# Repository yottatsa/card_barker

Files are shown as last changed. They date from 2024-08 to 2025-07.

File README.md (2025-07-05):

# Card Barker OPL3 Sound Card

*WARNING: this project has manufacturability issues: Zilog and two Yamaha chips are virtually unobtainable*

* PCMCIA interface: [Zilog Z86017/Z16017](https://www.zilog.com/index.php?Itemid=26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)
* OPL3: Yamaha YMF289B-S and YAC516-E
* Amp: [Texas Instruments TPA152DR](http://www.ti.com/lit/gpn/tpa152)

Project status: devboard is working, card hw rev 2 is working, card hw rev 3 goes thru small reDfM. 

## How to run

1. After assembly, upload `fw/vew211.bpd` using `fw/hsc.zip/burner.exe`;
2. Enable using `dos/panas13.lzh/panasnd.exe`, it should start responding on `0x0388-0x038b`;
3. Run `dos/oplclone.zip/oplclone.exe`, it should produce ~460Hz sine.
4. Under Windows 95 and 98, `win9x` contains the proto-driver that only enables the port.

## PCBs
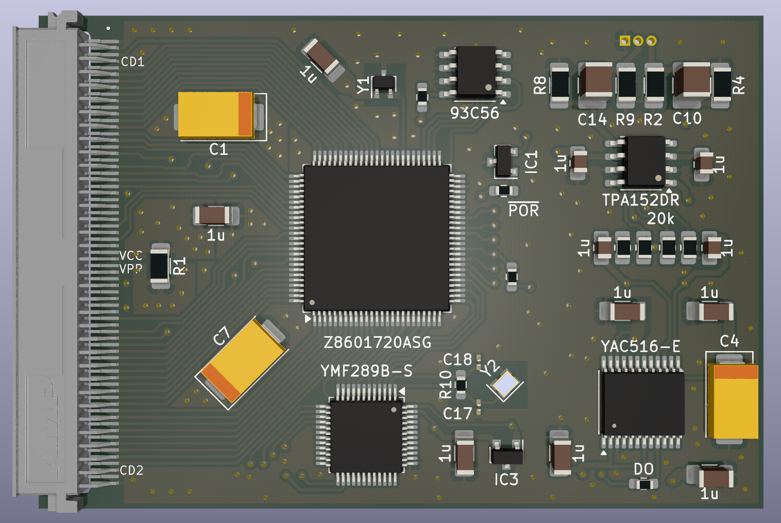
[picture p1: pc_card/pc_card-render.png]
Card

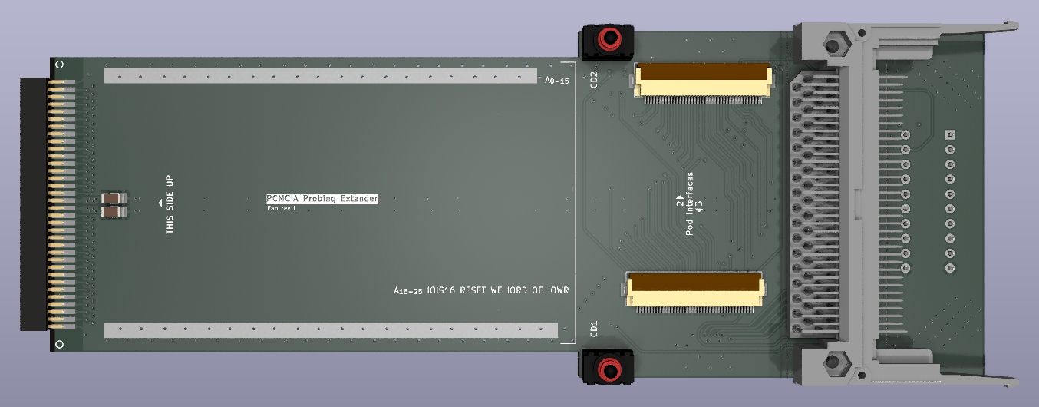
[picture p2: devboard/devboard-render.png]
devboard

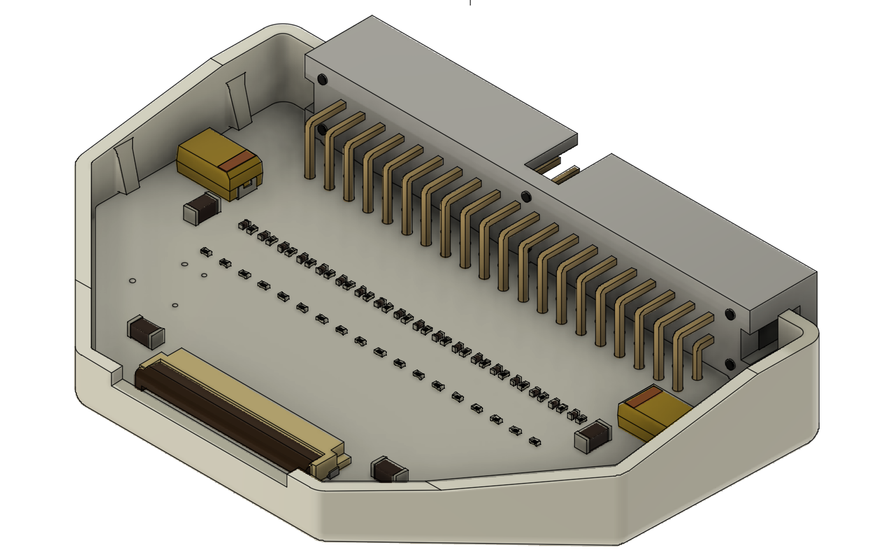
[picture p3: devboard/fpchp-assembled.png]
pod adapter


## Related projects

* [FMC-98 reverse engineering](https://github.com/AL-255/A2P1)

## License

Code, designs, and original research: CERN Open Hardware Licence Version 2 - Strongly Reciprocal
Supporting materials: fair use (archived to be protected from bitrot)

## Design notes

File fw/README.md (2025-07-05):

# Firmware misc

## `main.py` and `fw.bpd`
Fully generated driver

## `vew211*`

CIS dump for Panasonic Sound Card CF-VEW211.

## `hsc.zip`

3rd-party software that includes `BURNER.EXE`, utility to program the 93C56 EEPROM in-situ. Note that it should be run without Card Services running.

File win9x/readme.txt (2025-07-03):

pccard.inf
==========

This is a sample driver that should work with Panasonic CF-VEW211 card (see ../fw/vew211*) and generated driver (../fw/fw.bpd). The driver is generated using INF File Editor based on MSDN Library April 2000, https://library.thedatadungeon.com/msdn-2000-04/win95ddk/devdoc/live/win98ddk/devinst_12yd.htm and Windows 95 DDK docs/pnp.doc, https://archive.org/download/ms-win95-ddk.

todo
----
- figure out overrides, https://library.thedatadungeon.com/msdn-2000-04/win95ddk/devdoc/live/win98ddk/pnp_0hti.htm
- check if LogConfig is needed

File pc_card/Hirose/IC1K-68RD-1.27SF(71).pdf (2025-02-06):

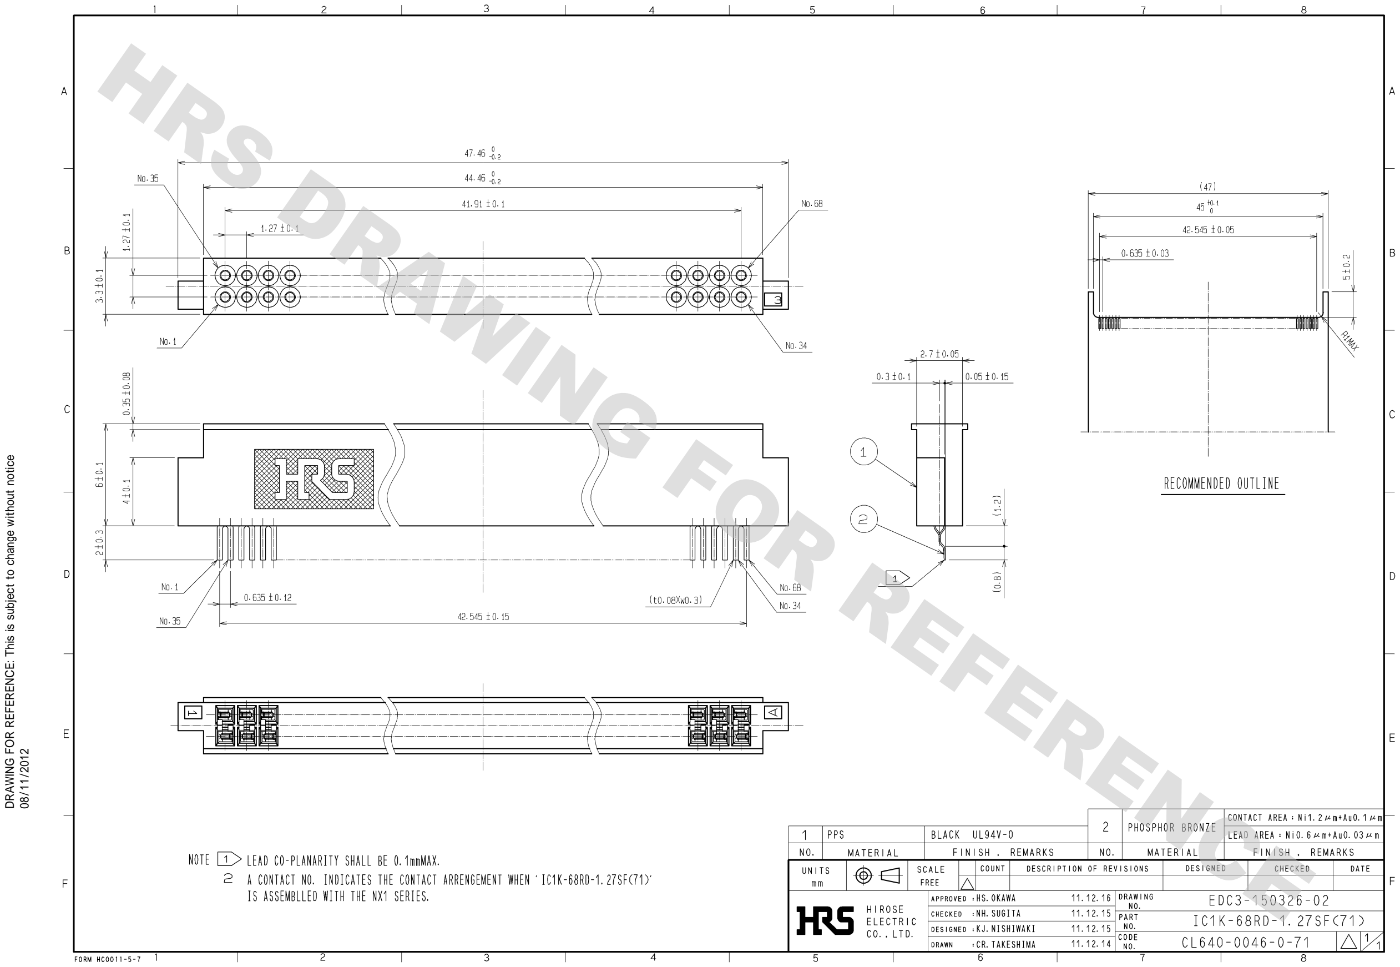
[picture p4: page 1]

# HRS DRAWING FOR REFERENCE

DRAWING FOR REFERENCE: This is subject to change without notice

08/11/2012

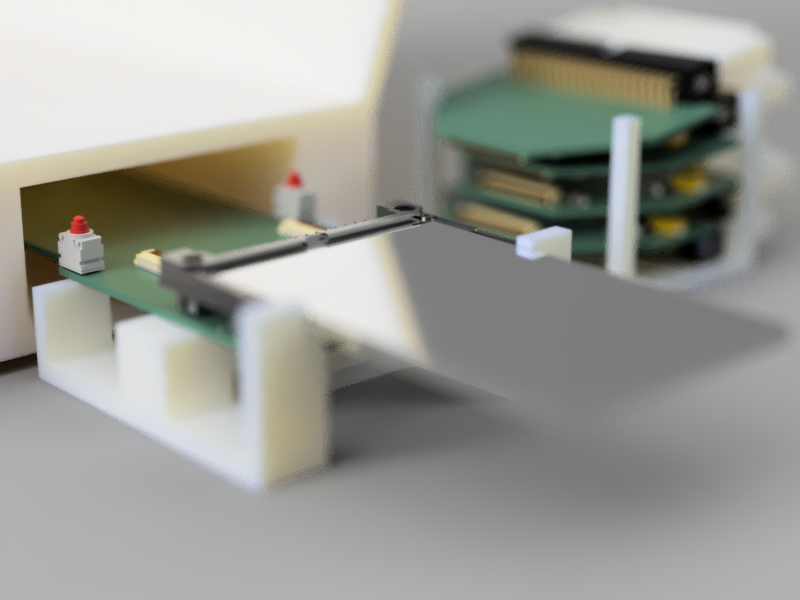
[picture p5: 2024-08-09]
devboard/dut_render.png

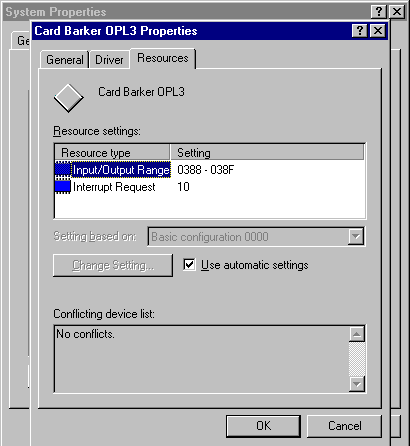
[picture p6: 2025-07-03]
win9x/sysprop-res.gif

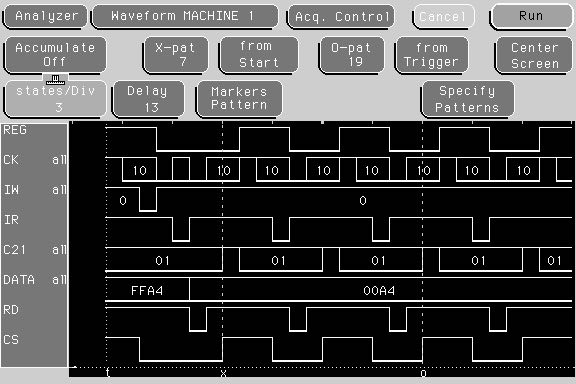
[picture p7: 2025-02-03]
hp1661c/waveform.jpg

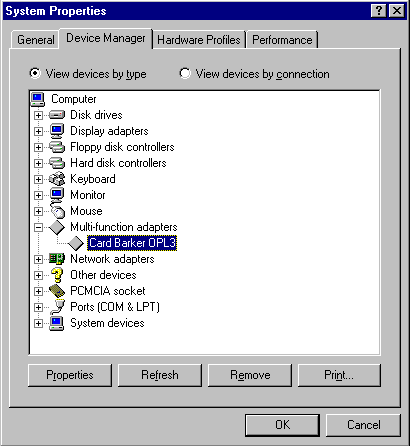
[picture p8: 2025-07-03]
win9x/sysprop.gif

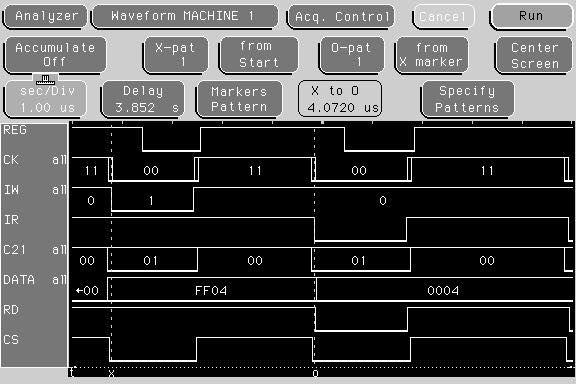
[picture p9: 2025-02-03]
hp1661c/timings.jpg

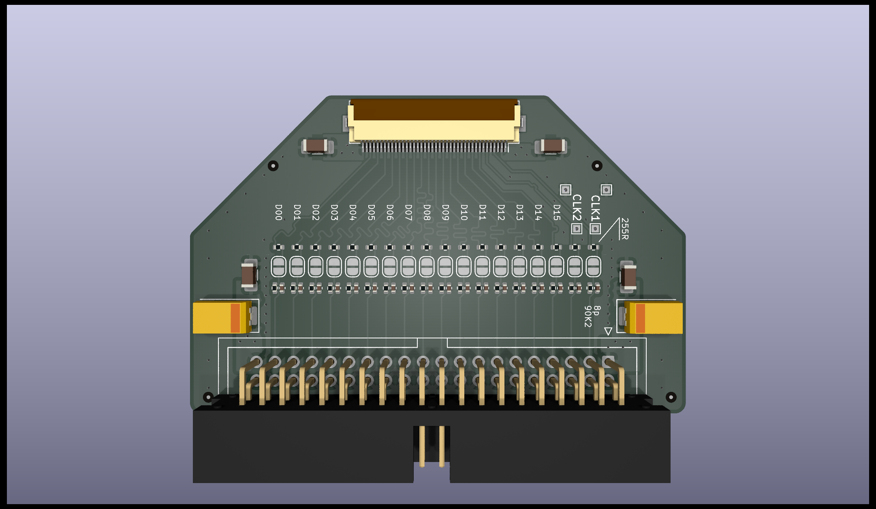
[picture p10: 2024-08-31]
devboard/fpchp-render.png

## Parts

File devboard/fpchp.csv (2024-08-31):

Id | Designator | Footprint | Quantity | Designation | Supplier and ref
1 | C15,C9,C7,C16,C5,C12,C8,C11,C2,C4,C10,C18,C3,C17,C14,C1,C13,C6 | C_0402_1005Metric | 18 | 8.2pF 0402 SMD Capacitor
2 | R24,R8,R19,R28,R32,R20,R12,R3,R16,R4,R7,R15,R27,R23,R11,R36,R31,R35 | R_0402_1005Metric | 18 | 249.0Ω 0402 SMD Resistor
3 | J1 | Hirose_FH12-40S-0.5SH_1x40-1MP_P0.50mm_Horizontal | 1 | Hirose Electric Co Ltd FH12A-40S-0.5SH(55)
4 | R30,R17,R14,R9,R34,R29,R25,R22,R6,R18,R26,R5,R13,R33,R2,R21,R1,R10 | R_0402_1005Metric | 18 | 90.9kΩ 0402 SMD Resistor
5 | C22,C19,C21,C20 | C_1206_3216Metric_Pad1.33x1.80mm_HandSolder | 4 | 1.0µF, 1206 SMD Capacitor
6 | CP2,CP1 | CP_EIA-7343-31_Kemet-D | 2 | 593D106X9035D2TE3 or other 10uF Electrolytic 16V or higher

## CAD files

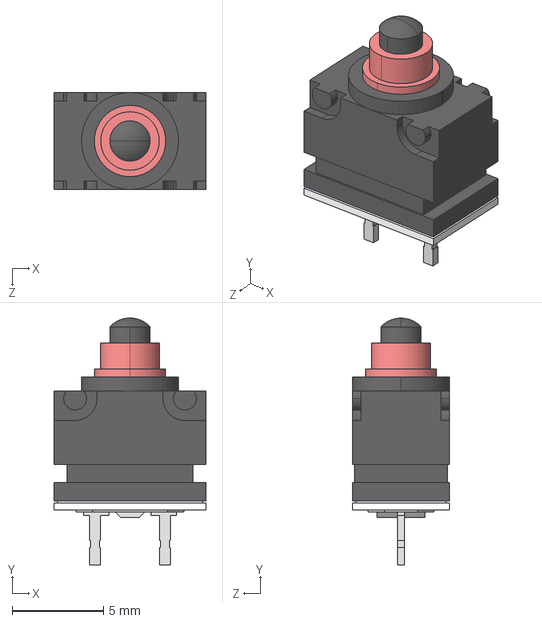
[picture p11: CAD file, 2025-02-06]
devboard/D2GW_A02D.step
8.30 x 13.5 x 5.30 mm
D2GW_A02D_BASE
D2GW_A02D_BUTTON

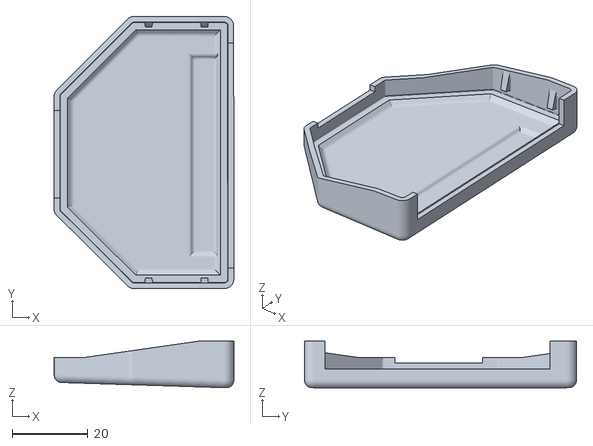
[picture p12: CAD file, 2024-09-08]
devboard/fpchp.stl
47.5 x 71.8 x 12.3

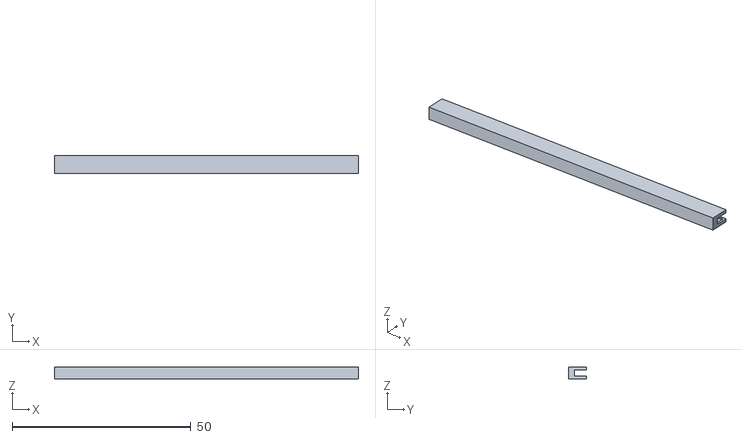
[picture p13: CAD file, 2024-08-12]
devboard/pcb_bracket.stl
85.0 x 5.00 x 3.30

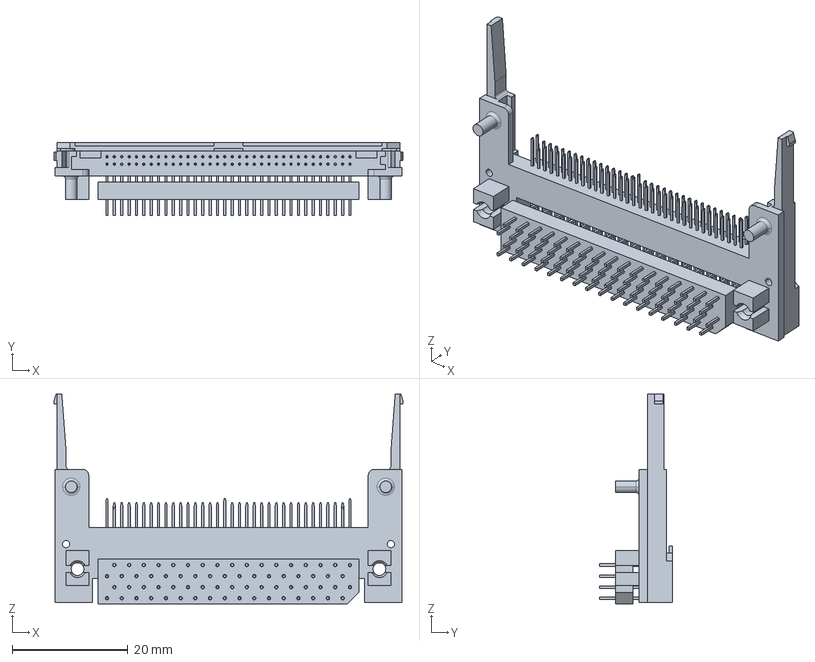
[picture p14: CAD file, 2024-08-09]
devboard/92140-010LF/92140-010LFc.stp
60.2 x 12.6 x 36.2 mm

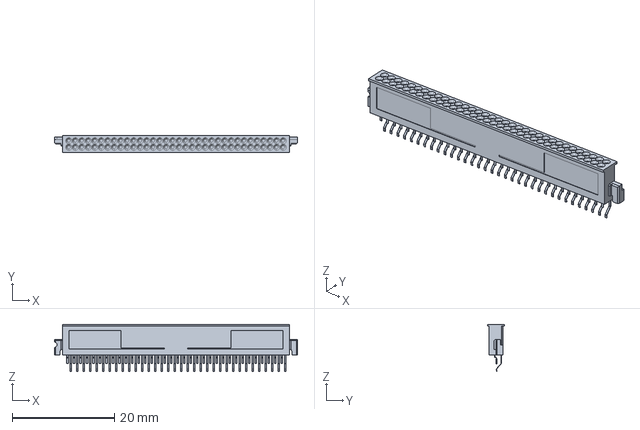
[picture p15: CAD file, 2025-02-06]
pc_card/TE/5146228-4.stp
47.5 x 3.30 x 9.25 mm

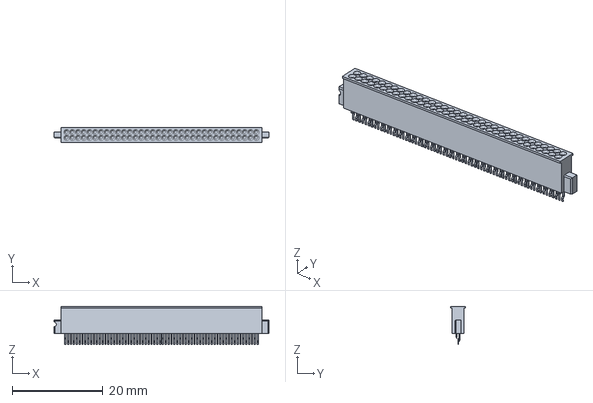
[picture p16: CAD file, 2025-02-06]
pc_card/TE/5146547-1.stp
47.5 x 3.30 x 8.48 mm

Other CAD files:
devboard/bottom-case.step

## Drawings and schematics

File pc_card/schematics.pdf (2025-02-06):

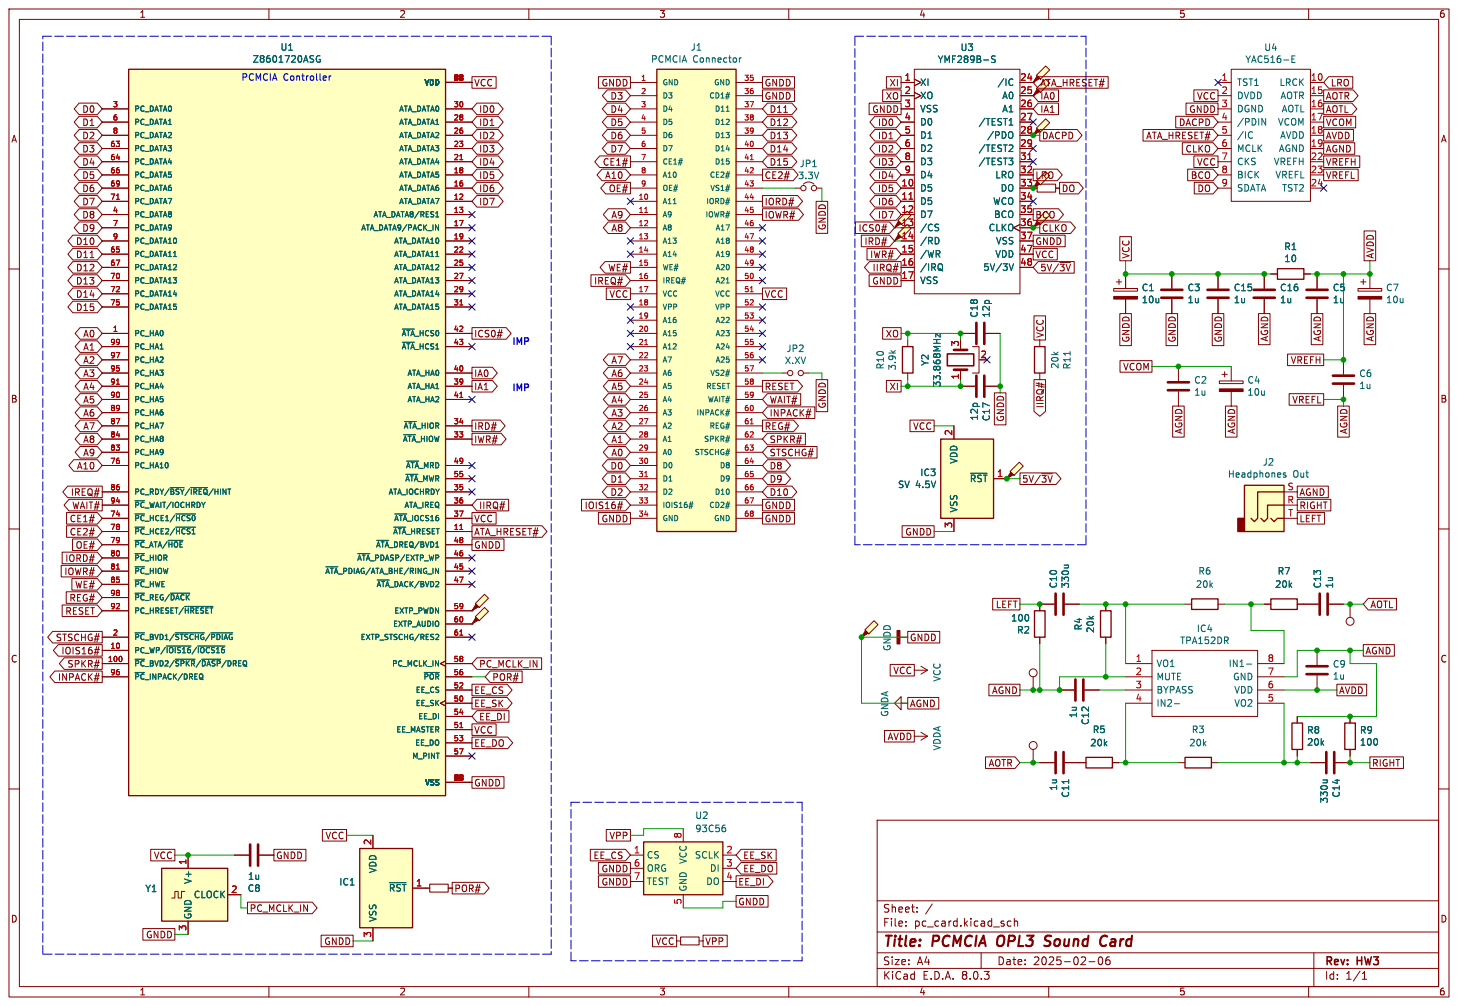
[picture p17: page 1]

INPACK# STSCHG# GNDD GNDD

Id: 1/1 Title: PCMCIA OPL3 Sound Card

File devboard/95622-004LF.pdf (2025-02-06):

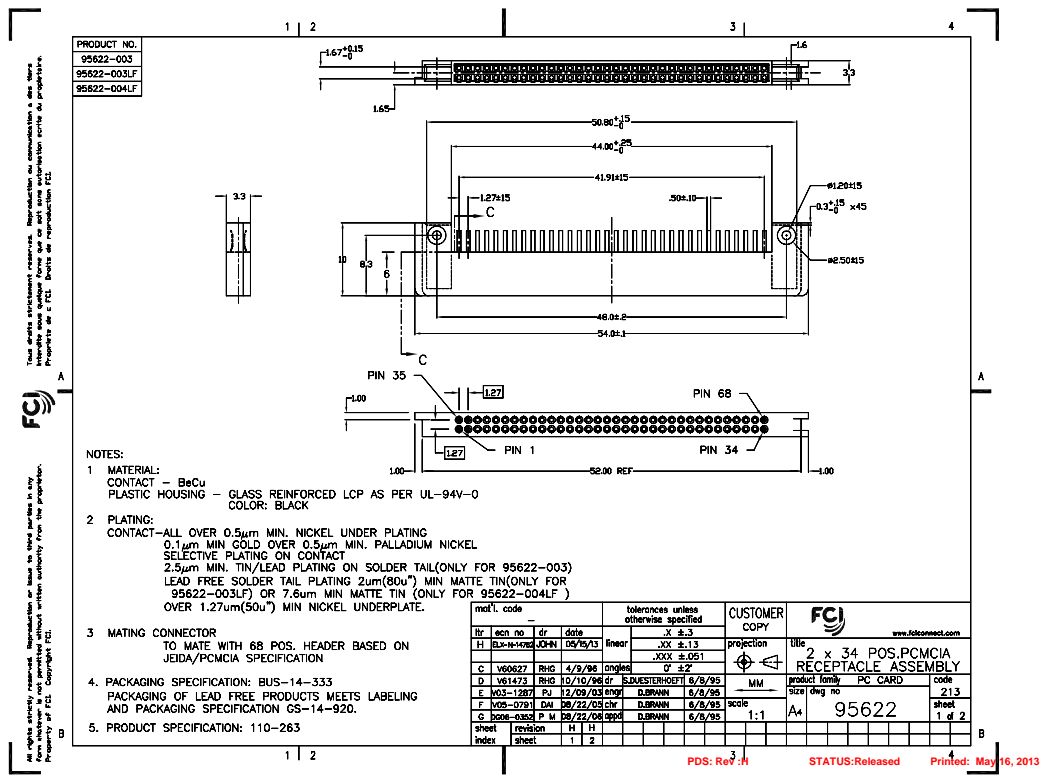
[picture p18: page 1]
PDS: Rev :H; STATUS:Released; Printed: May 16, 2013

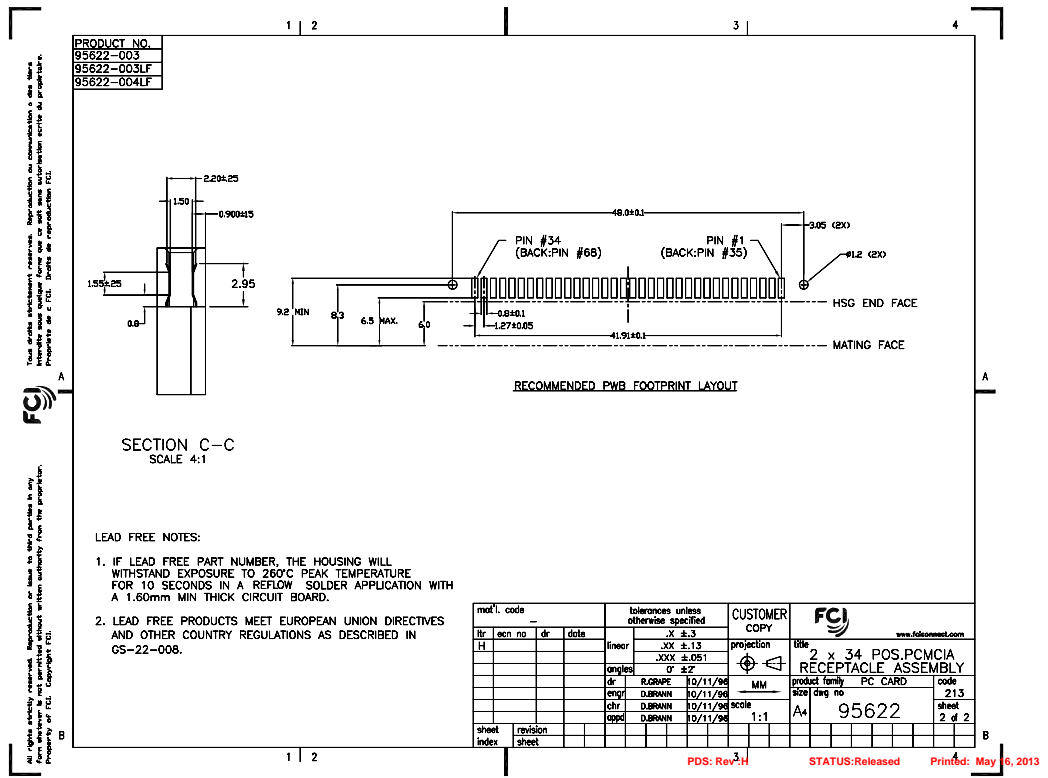
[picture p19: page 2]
PDS: Rev :H; STATUS:Released; Printed: May 16, 2013

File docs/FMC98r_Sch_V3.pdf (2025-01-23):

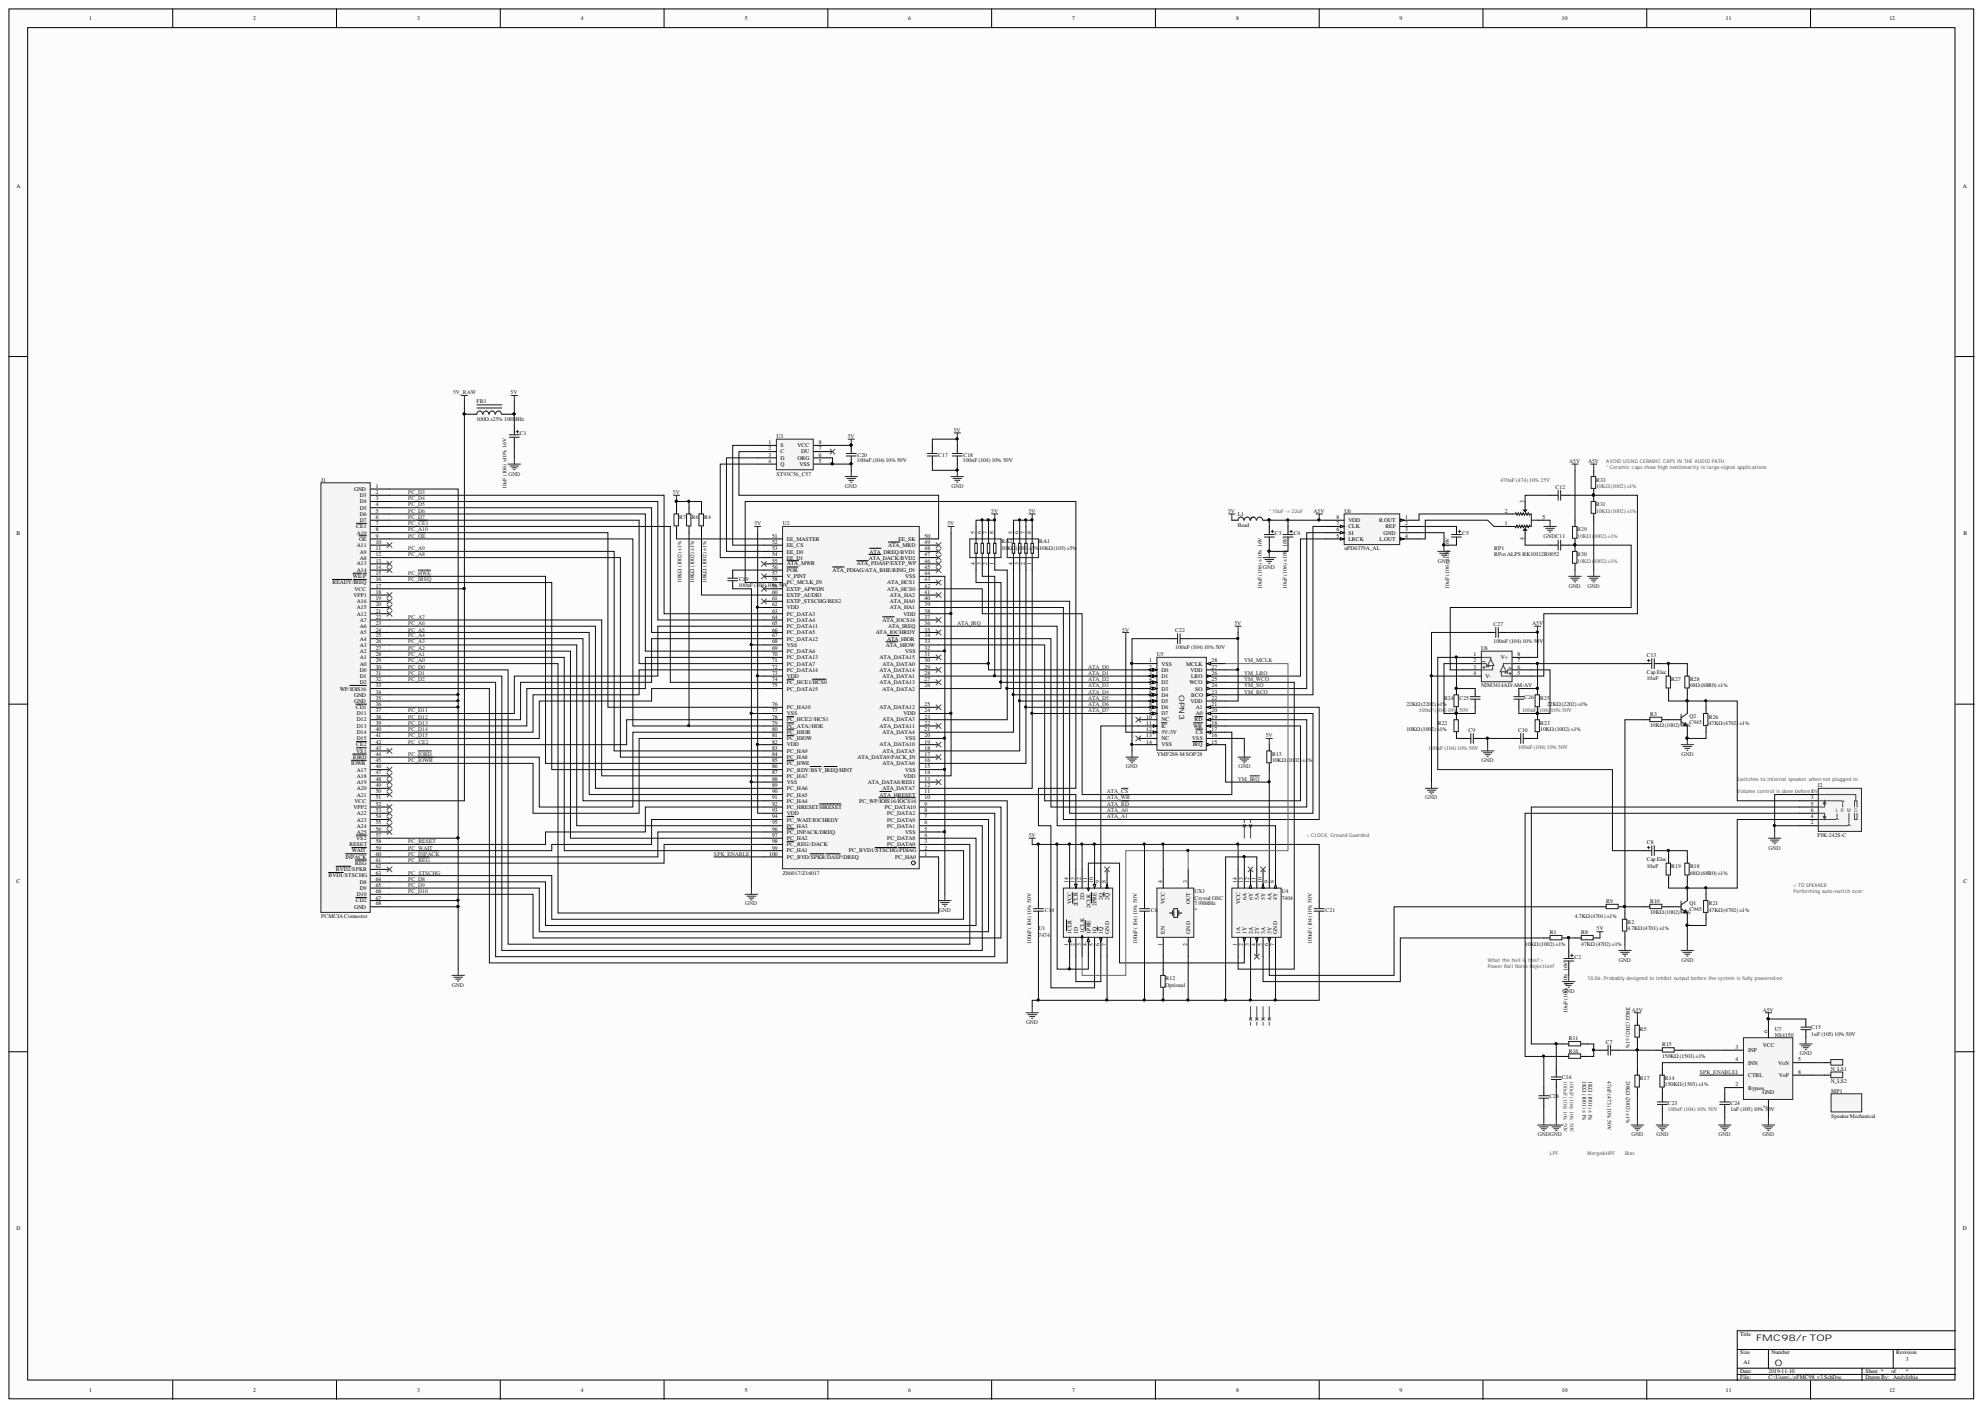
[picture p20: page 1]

150K Ω (1503) ±1% 4 | IN N VoN C T R L VoP Bypa s s D

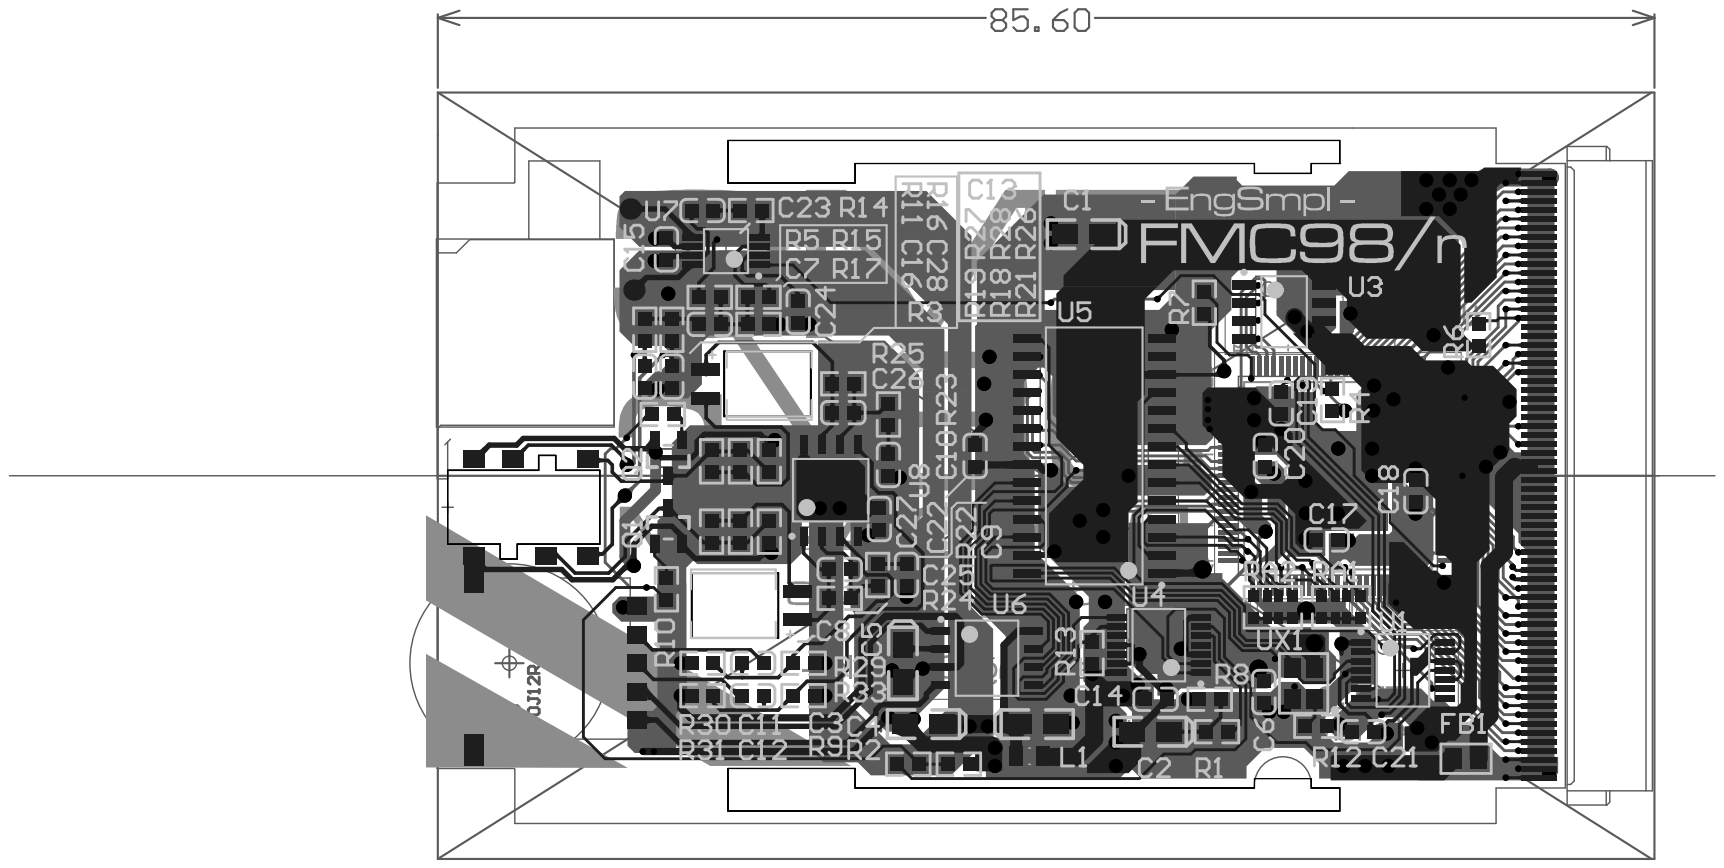
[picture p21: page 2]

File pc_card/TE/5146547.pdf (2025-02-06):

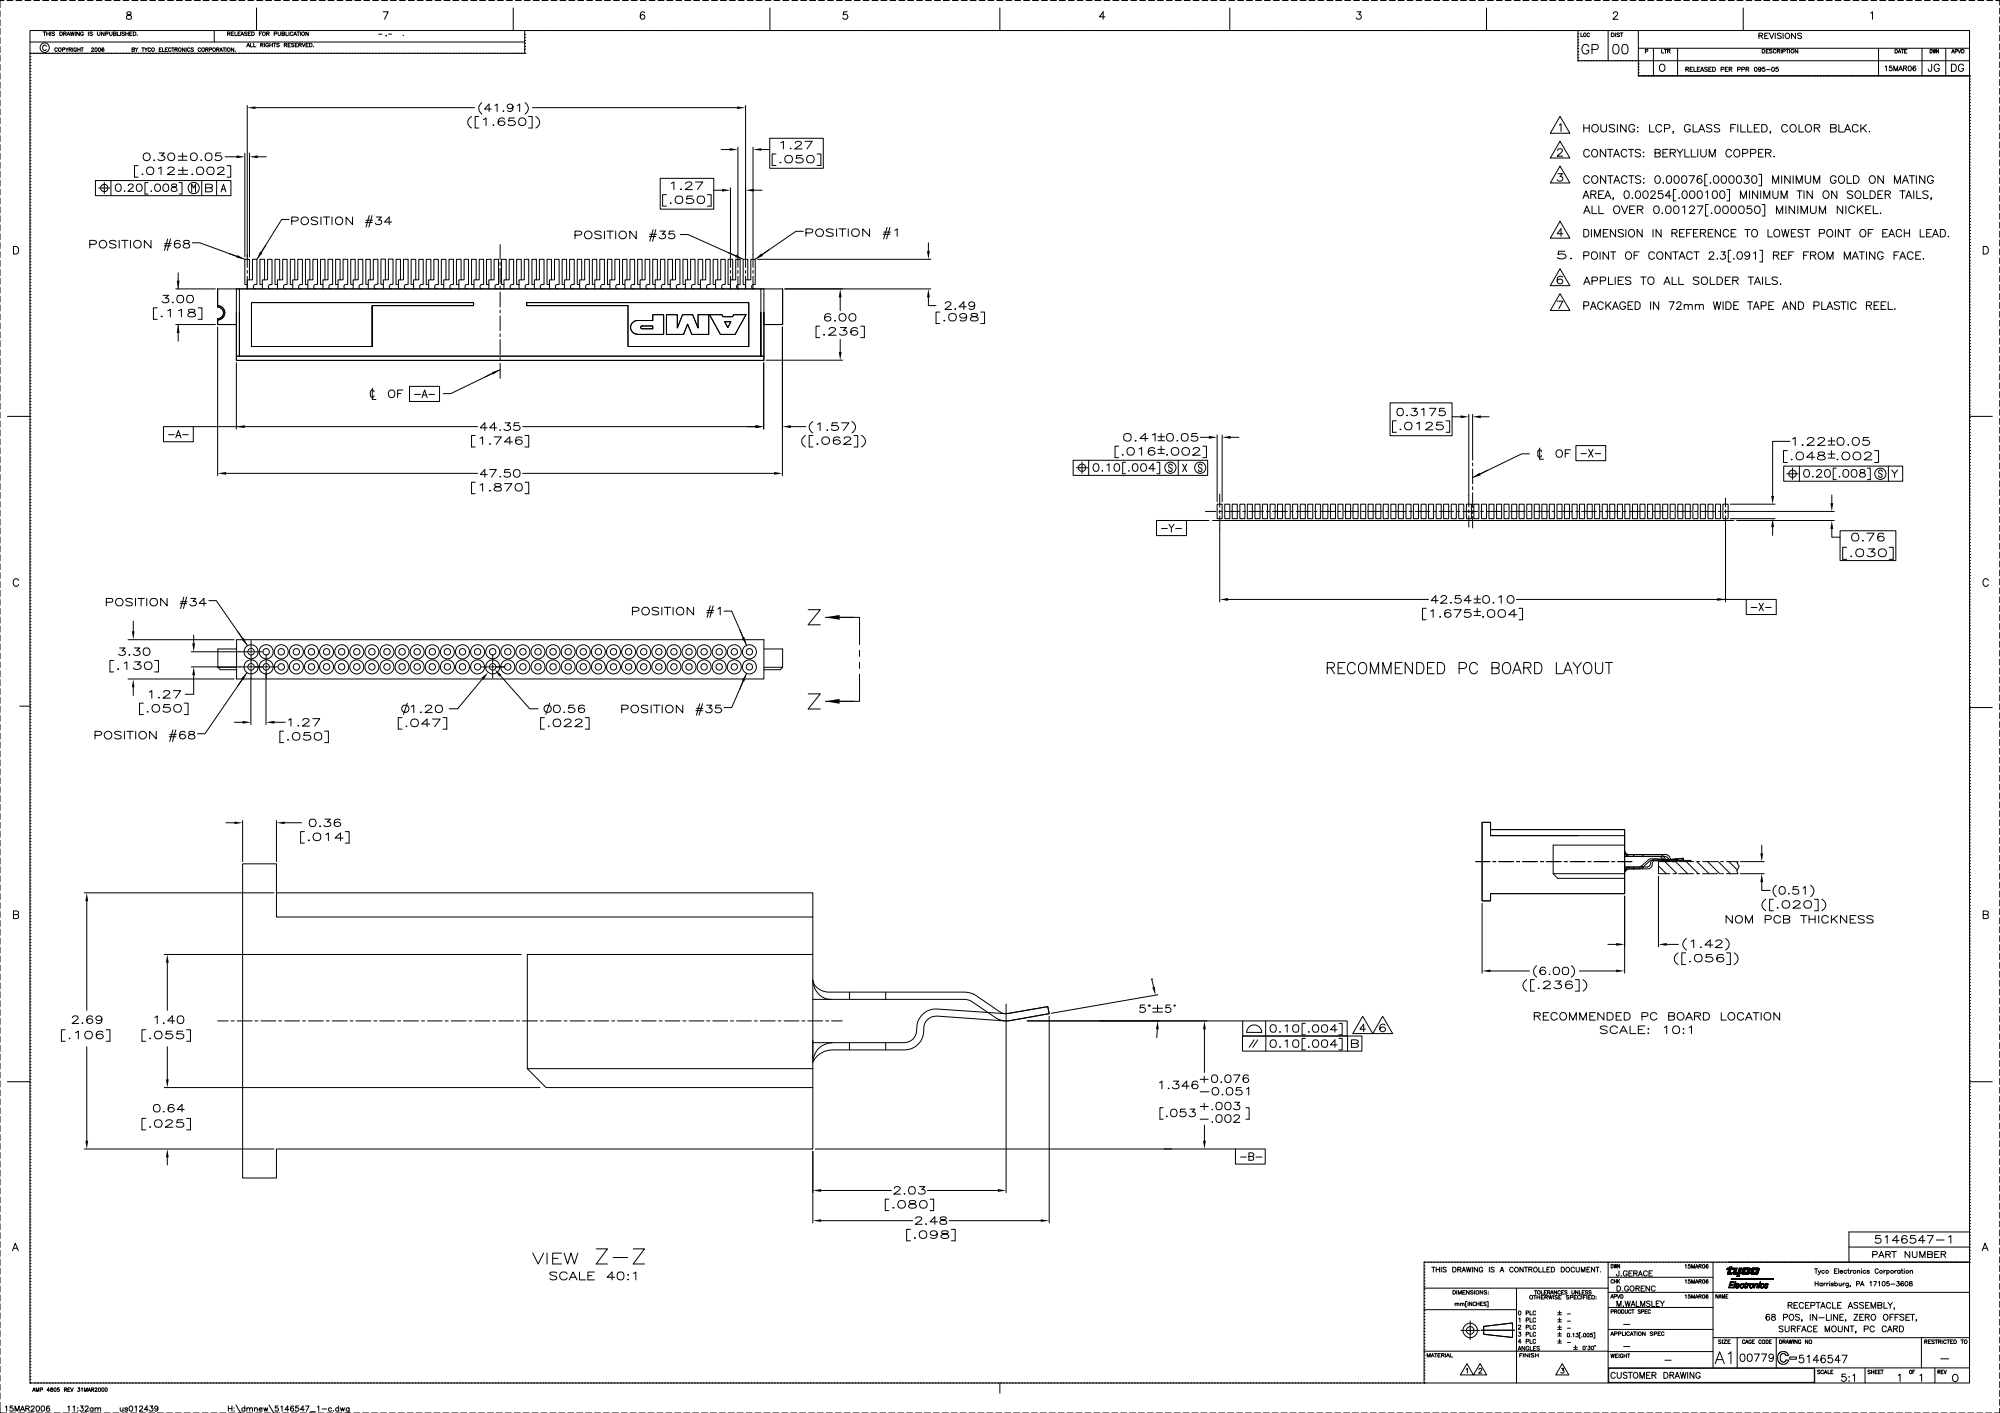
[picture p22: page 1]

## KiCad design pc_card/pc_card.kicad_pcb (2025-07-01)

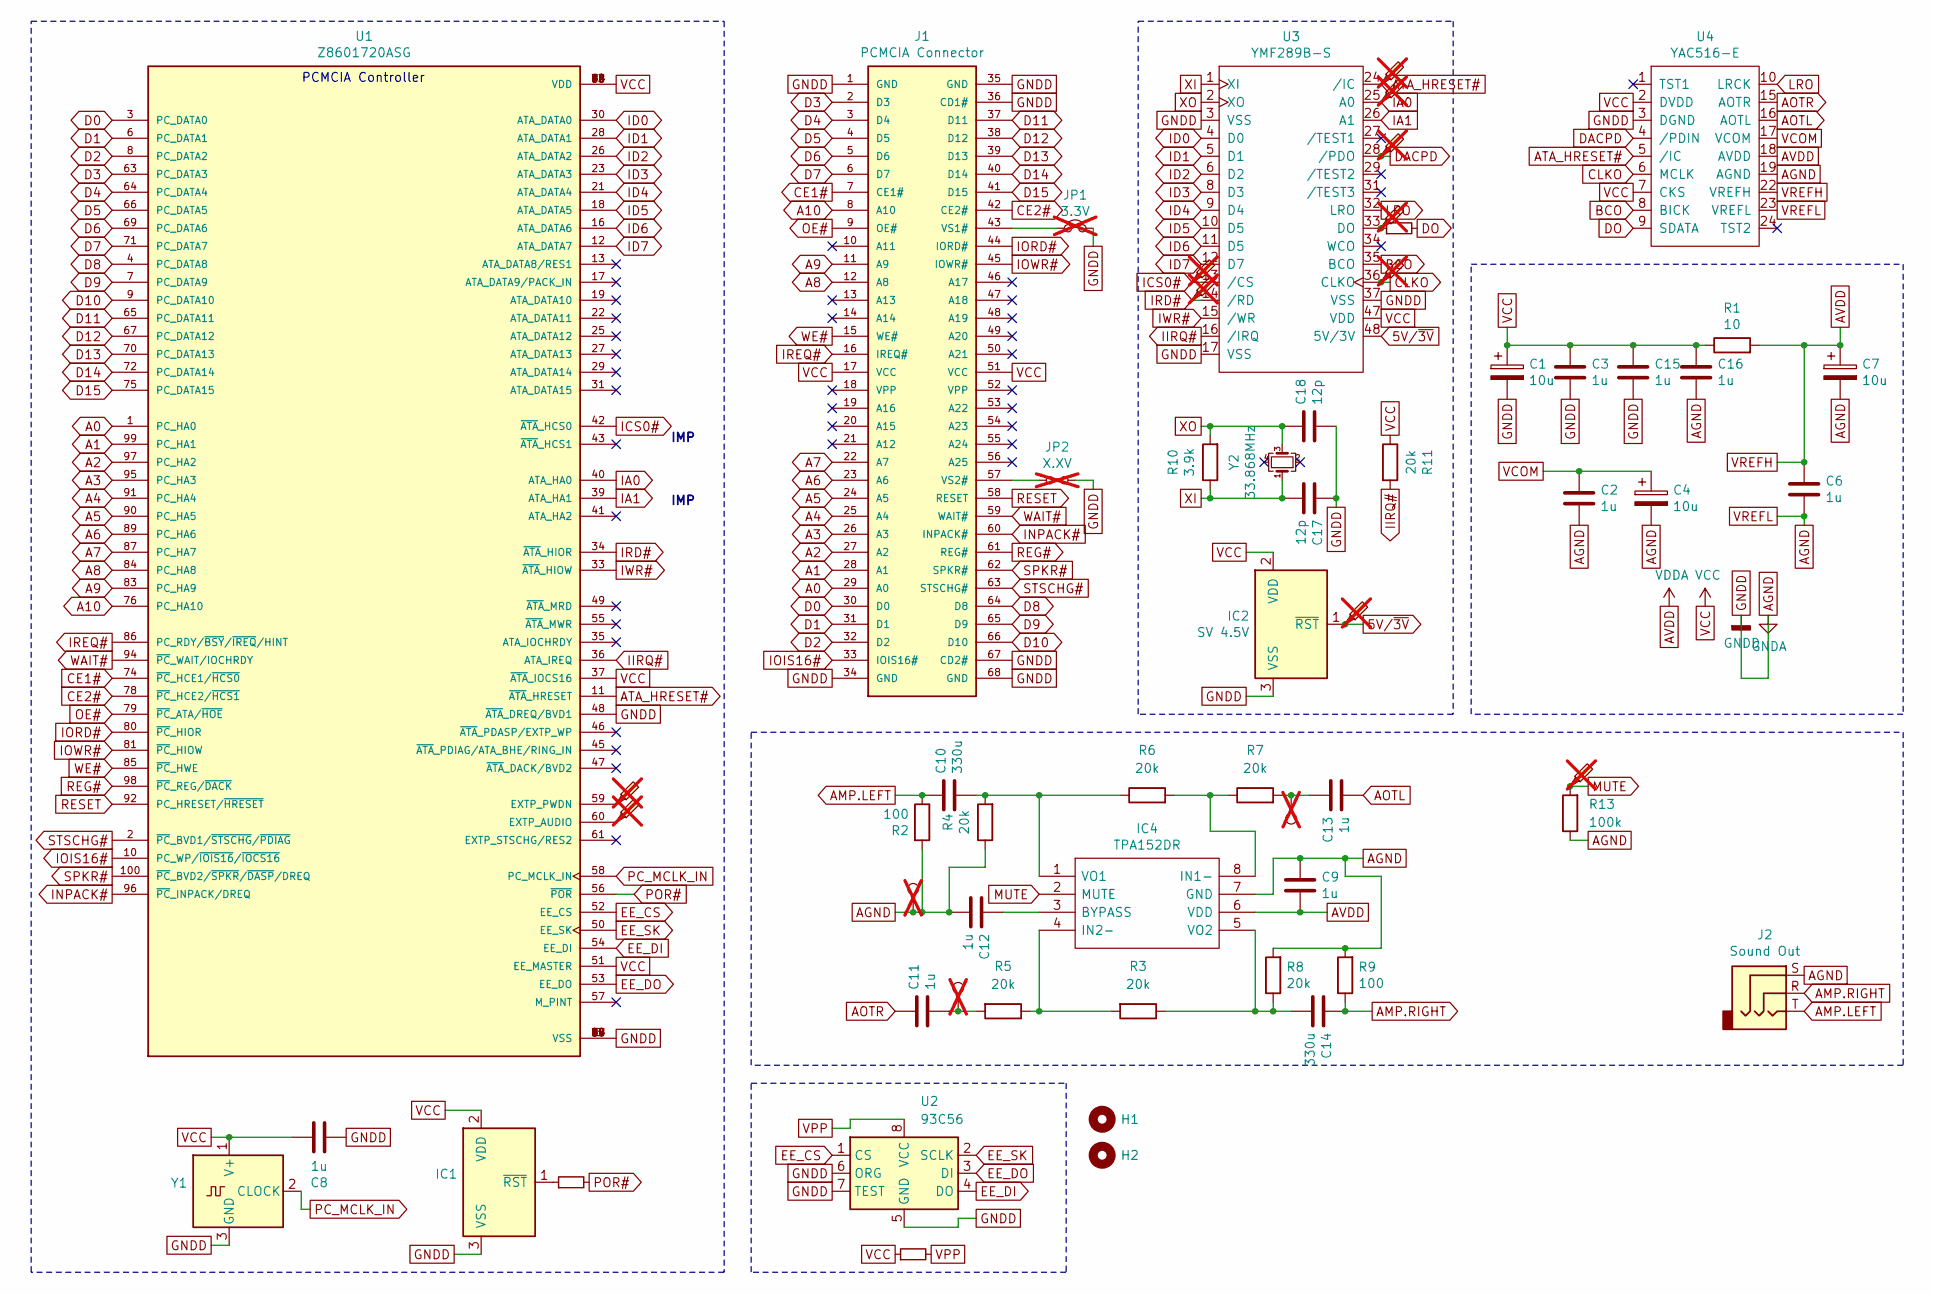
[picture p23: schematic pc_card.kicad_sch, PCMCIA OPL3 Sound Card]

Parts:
C1, C4, C7: 10u; CP_EIA-7343-15_Kemet-W_Pad2.25x2.55mm_HandSolder; Manufacturer_Part_Number EEF-CS1D100R; Mouser Part Number 667-EEF-CS1D100R
C2, C3, C6, C8, C15, C16: 1u; C_1206_3216Metric_Pad1.33x1.80mm_HandSolder; Manufacturer_Part_Number C1206X104G4HACTU; Mouser Part Number 80-C1206X104G4HACTU
C9, C11, C12, C13: 1u; C_0805_2012Metric_Pad1.18x1.45mm_HandSolder; Manufacturer_Part_Number C0805C105M3REC7210; Mouser Part Number 80-C0805C105M3RECLR
C10, C14: 330u; C_1210_3225Metric_Pad1.33x2.70mm_HandSolder; Manufacturer_Part_Number GRM32EC80E337ME05L; Mouser Part Number 81-GRM32EC80E337ME5L
C17, C18: 12p; C_0603_1608Metric_Pad1.08x0.95mm_HandSolder; Manufacturer_Part_Number 0603ZA120JAT2A; Mouser Part Number 581-0603ZA120JAT2A
H1, H2: MountingHole
IC1: SV 3.3V; SOT-23; Manufacturer_Part_Number TLV803EB33VDBZR; Mouser Part Number 595-TLV803EB33VDBZR
IC2: SV 4.5V; SOT-23; Manufacturer_Part_Number MCP102T-450E/TT
IC4: TPA152DR; SOIC-8_3.9x4.9mm_P1.27mm; Mouser Part Number 595-TPA152DR
J1: PCMCIA Connector; IC1F-68RD-1.27SF(52); Manufacturer_Part_Number IC1F-68RD-1.27SF(52); Mouser Part Number 798-IC1F68RD127SF52
J2: Sound Out; CUI_SJ1-2533-SMT-TR
JP1: 3.3V; SolderJumper-2_P1.3mm_Bridged_RoundedPad1.0x1.5mm; not fitted
JP2: X.XV; SolderJumper-2_P1.3mm_Open_RoundedPad1.0x1.5mm; not fitted
R1: 10; R_1206_3216Metric_Pad1.30x1.75mm_HandSolder
R2, R9: 100; R_1206_3216Metric_Pad1.30x1.75mm_HandSolder; Manufacturer_Part_Number ERJ-U02F3901X; Mouser Part Number 667-ERJ-U02F3901X
R3, R5, R6, R7: 20k; R_0805_2012Metric_Pad1.20x1.40mm_HandSolder
R4, R8: 20k; R_1206_3216Metric_Pad1.30x1.75mm_HandSolder
R10: 3.9k; R_0603_1608Metric_Pad0.98x0.95mm_HandSolder
R11: 20k; R_0603_1608Metric_Pad0.98x0.95mm_HandSolder
R12: EEPROM; R_0603_1608Metric_Pad0.98x0.95mm_HandSolder
R13: 100k; R_0805_2012Metric_Pad1.20x1.40mm_HandSolder
R14: DO; R_0603_1608Metric_Pad0.98x0.95mm_HandSolder
R15: ~{POR}; R_0603_1608Metric_Pad0.98x0.95mm_HandSolder
TP1: R; TestPoint_Pad_D1.0mm; not fitted
TP2: L; TestPoint_Pad_D1.0mm; not fitted
TP3: ~{CS}; TestPoint_Pad_1.0x1.0mm; not fitted
TP4: GND; TestPoint_Pad_D1.0mm; not fitted
TP5: AMP; TestPoint_Pad_1.0x1.0mm; not fitted
TP6: PWDN; TestPoint_Pad_1.0x1.0mm; not fitted
TP7: AUDIO; TestPoint_Pad_1.0x1.0mm; not fitted
TP8: 5V/~{3V}; TestPoint_Pad_1.0x1.0mm; not fitted
TP9: DO; TestPoint_Pad_1.0x1.0mm; not fitted
TP10: ~{RD}; TestPoint_Pad_1.0x1.0mm; not fitted
TP11: CK; TestPoint_Pad_1.0x1.0mm; not fitted
TP12: ~{PD}; TestPoint_Pad_1.0x1.0mm; not fitted
TP13: A0; TestPoint_Pad_1.0x1.0mm; not fitted
TP14: ~{RESET}; TestPoint_Pad_1.0x1.0mm; not fitted
U1: Z8601720ASG; LQFP-100_14x14mm_P0.5mm; PARTREV Jan, 2005
U2: 93C56; SOIC-8_3.9x4.9mm_P1.27mm; Manufacturer_Part_Number 93C56
U3: YMF289B-S; TQFP-48_7x7mm_P0.5mm; Manufacturer_Part_Number YMF289B-S
U4: YAC516-E; TSSOP-24_6.1x7.8mm_P0.65mm; Manufacturer_Part_Number YAC516-E
Y1: 8MHZ; SOT-323_SC-70; Manufacturer_Part_Number MAX7375AXR805+T; Mouser Part Number 700-MAX7375AXR425T
Y2: 33.868MHz; Crystal_SMD_2520-4Pin_2.5x2.0mm; Manufacturer_Part_Number XRCGB33M868F4M00R0; Mouser Part Number 81-XRCGB33M868F4M0R0

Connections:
5V/~3V: IC2.1 (~RST), TP8.1, U3.48 (5V/3V)
A0: J1.29 (A0), U1.1 (PC_HA0)
A1: J1.28 (A1), U1.99 (PC_HA1)
A2: J1.27 (A2), U1.97 (PC_HA2)
A3: J1.26 (A3), U1.95 (PC_HA3)
A4: J1.25 (A4), U1.91 (PC_HA4)
A5: J1.24 (A5), U1.90 (PC_HA5)
A6: J1.23 (A6), U1.89 (PC_HA6)
A7: J1.22 (A7), U1.87 (PC_HA7)
A8: J1.12 (A8), U1.84 (PC_HA8)
A9: J1.11 (A9), U1.83 (PC_HA9)
A10: J1.8 (A10), U1.76 (PC_HA10)
AGND: C1.2, C2.2, C3.2, C4.2, C6.2, C7.2, C8.1, C9.1, C12.2, C15.2, C16.2, C17.1, C18.2, IC1.3 (VSS), IC2.3 (VSS), IC4.7 (GND), J1.1 (GND), J1.34 (GND), J1.35 (GND), J1.36 (CD1#), J1.67 (CD2#), J1.68 (GND), J2.S, JP1.2, JP2.2, R2.2, R4.1, R8.2, R9.2, R13.1, TP4.1, U1.5 (VSS), U1.15 (VSS), U1.20 (VSS), U1.32 (VSS), U1.44 (VSS), U1.48 (~ATA_DREQ/BVD1), U1.68 (VSS), U1.77 (VSS), U1.88 (VSS), U2.5 (GND), U2.6 (ORG), U2.7 (TEST), U3.3 (VSS), U3.17 (VSS), U3.37 (VSS), U4.3 (DGND), U4.19 (AGND), U4.23 (VREFL), Y1.3 (GND)
AMP.LEFT: C10.1, J2.T, R2.1
AMP.RIGHT: C14.1, J2.R, R9.1
AOTL: C13.2, U4.16 (AOTL)
AOTR: C11.1, U4.15 (AOTR)
ATA_HRESET#: TP14.1, U1.11 (~ATA_HRESET), U3.24 (/IC), U4.5 (/IC)
AVDD: C6.1, C7.1, C9.2, IC4.6 (VDD), R1.2, U4.18 (AVDD), U4.22 (VREFH)
BCO: U3.35 (BCO), U4.8 (BICK)
CE1#: J1.7 (CE1#), U1.74 (~PC_HCE1/~HCS0)
CE2#: J1.42 (CE2#), U1.78 (~PC_HCE2/~HCS1)
CLKO: TP11.1, U3.36 (CLKO), U4.6 (MCLK)
D0: J1.30 (D0), U1.3 (PC_DATA0)
D1: J1.31 (D1), U1.6 (PC_DATA1)
D2: J1.32 (D2), U1.8 (PC_DATA2)
D3: J1.2 (D3), U1.63 (PC_DATA3)
D4: J1.3 (D4), U1.64 (PC_DATA4)
D5: J1.4 (D5), U1.66 (PC_DATA5)
D6: J1.5 (D6), U1.69 (PC_DATA6)
D7: J1.6 (D7), U1.71 (PC_DATA7)
D8: J1.64 (D8), U1.4 (PC_DATA8)
D9: J1.65 (D9), U1.7 (PC_DATA9)
D10: J1.66 (D10), U1.9 (PC_DATA10)
D11: J1.37 (D11), U1.65 (PC_DATA11)
D12: J1.38 (D12), U1.67 (PC_DATA12)
D13: J1.39 (D13), U1.70 (PC_DATA13)
D14: J1.40 (D14), U1.72 (PC_DATA14)
D15: J1.41 (D15), U1.75 (PC_DATA15)
DACPD: TP12.1, U3.28 (/PDO), U4.4 (/PDIN)
DO: R14.2, U4.9 (SDATA)
EE_CS: U1.52 (EE_CS), U2.1 (CS)
EE_DI: U1.54 (EE_DI), U2.4 (DO)
EE_DO: U1.53 (EE_DO), U2.3 (DI)
EE_SK: U1.50 (EE_SK), U2.2 (SCLK)
IA0: TP13.1, U1.40 (ATA_HA0), U3.25 (A0)
IA1: U1.39 (ATA_HA1), U3.26 (A1)
ICS0#: TP3.1, U1.42 (~ATA_HCS0), U3.13 (/CS)
ID0: U1.30 (ATA_DATA0), U3.4 (D0)
ID1: U1.28 (ATA_DATA1), U3.5 (D1)
ID2: U1.26 (ATA_DATA2), U3.6 (D2)
ID3: U1.23 (ATA_DATA3), U3.8 (D3)
ID4: U1.21 (ATA_DATA4), U3.9 (D4)
ID5: U1.18 (ATA_DATA5), U3.10 (D5)
ID6: U1.16 (ATA_DATA6), U3.11 (D5)
ID7: U1.12 (ATA_DATA7), U3.12 (D7)
IIRQ#: R11.2, U1.36 (ATA_IREQ), U3.16 (/IRQ)
INPACK#: J1.60 (INPACK#), U1.96 (~PC_INPACK/DREQ)
IOIS16#: J1.33 (IOIS16#), U1.10 (PC_WP/~IOIS16/~IOCS16)
IORD#: J1.44 (IORD#), U1.80 (~PC_HIOR)
IOWR#: J1.45 (IOWR#), U1.81 (~PC_HIOW)
IRD#: TP10.1, U1.34 (~ATA_HIOR), U3.14 (/RD)
IREQ#: J1.16 (IREQ#), U1.86 (PC_RDY/~BSY/~IREQ/HINT)
IWR#: U1.33 (~ATA_HIOW), U3.15 (/WR)
LRO: U3.32 (LRO), U4.10 (LRCK)
MUTE: IC4.2 (MUTE), R13.2, TP5.1
unnamed: C11.2, R5.2, TP1.1
unnamed: C13.1, R7.2, TP2.1
unnamed: IC1.1 (~RST), R15.1
unnamed: C12.1, IC4.3 (BYPASS)
unnamed: IC4.8 (IN1-), R6.2, R7.1
unnamed: IC4.4 (IN2-), R3.2, R5.1
unnamed: C10.2, IC4.1 (VO1), R4.2, R6.1
unnamed: C14.2, IC4.5 (VO2), R3.1, R8.1
unnamed: J1.43 (VS1#), JP1.1
unnamed: J1.57 (VS2#), JP2.1
unnamed: TP7.1, U1.60 (EXTP_AUDIO)
unnamed: TP6.1, U1.59 (EXTP_PWDN)
unnamed: R14.1, TP9.1, U3.33 (DO)
OE#: J1.9 (OE#), U1.79 (~PC_ATA/~HOE)
PC_MCLK_IN: U1.58 (PC_MCLK_IN), Y1.2 (CLOCK)
POR#: R15.2, U1.56 (~POR)
REG#: J1.61 (REG#), U1.98 (~PC_REG/~DACK)
RESET: J1.58 (RESET), U1.92 (PC_HRESET/~HRESET)
SPKR#: J1.62 (SPKR#), U1.100 (~PC_BVD2/~SPKR/~DASP/DREQ)
STSCHG#: J1.63 (STSCHG#), U1.2 (~PC_BVD1/~STSCHG/~PDIAG)
VCC: C1.1, C3.1, C8.2, C15.1, C16.1, IC1.2 (VDD), IC2.2 (VDD), J1.17 (VCC), J1.51 (VCC), R1.1, R11.1, R12.1, U1.14 (VDD), U1.24 (VDD), U1.37 (~ATA_IOCS16), U1.38 (VDD), U1.51 (EE_MASTER), U1.62 (VDD), U1.73 (VDD), U1.82 (VDD), U1.93 (VDD), U3.47 (VDD), U4.2 (DVDD), U4.7 (CKS), Y1.1 (V+)
VCOM: C2.1, C4.1, U4.17 (VCOM)
VPP: R12.2, U2.8 (VCC)
WAIT#: J1.59 (WAIT#), U1.94 (~PC_WAIT/IOCHRDY)
WE#: J1.15 (WE#), U1.85 (~PC_HWE)
XI: C17.2, R10.1, U3.1 (XI), Y2.1
XO: C18.1, R10.2, U3.2 (XO), Y2.3

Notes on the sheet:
IMP
PCMCIA Controller

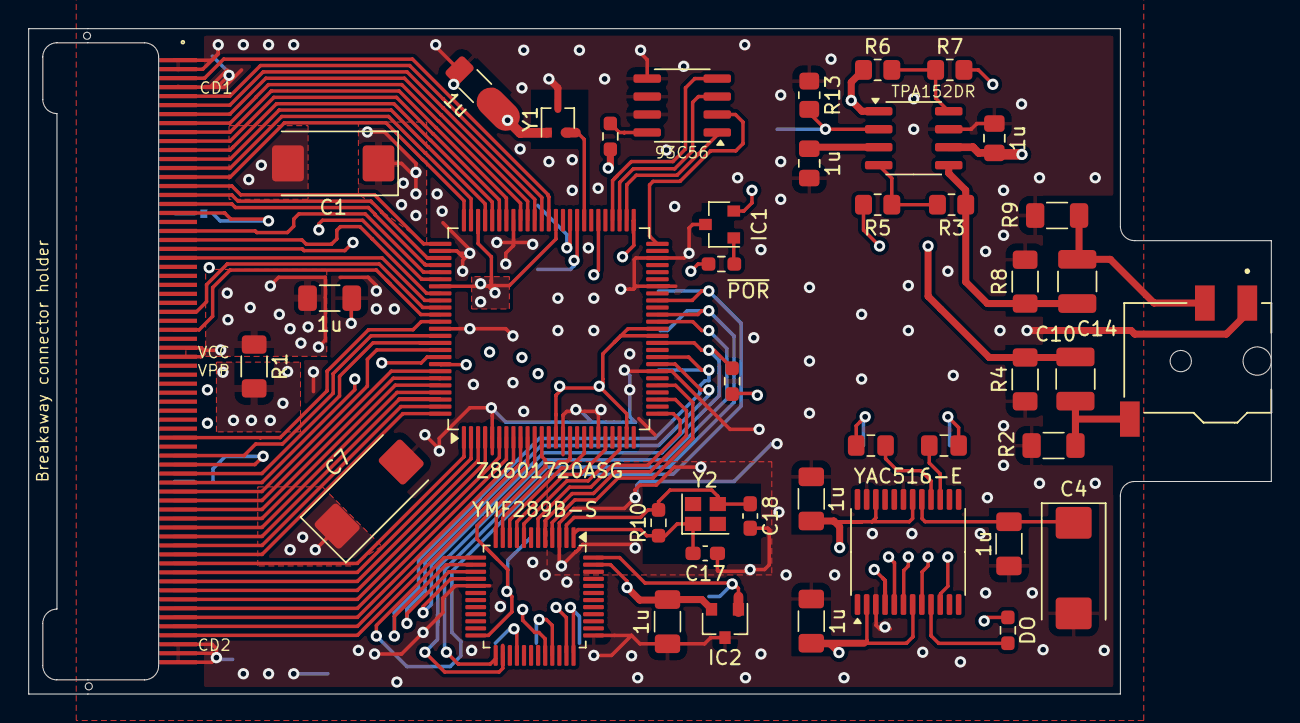
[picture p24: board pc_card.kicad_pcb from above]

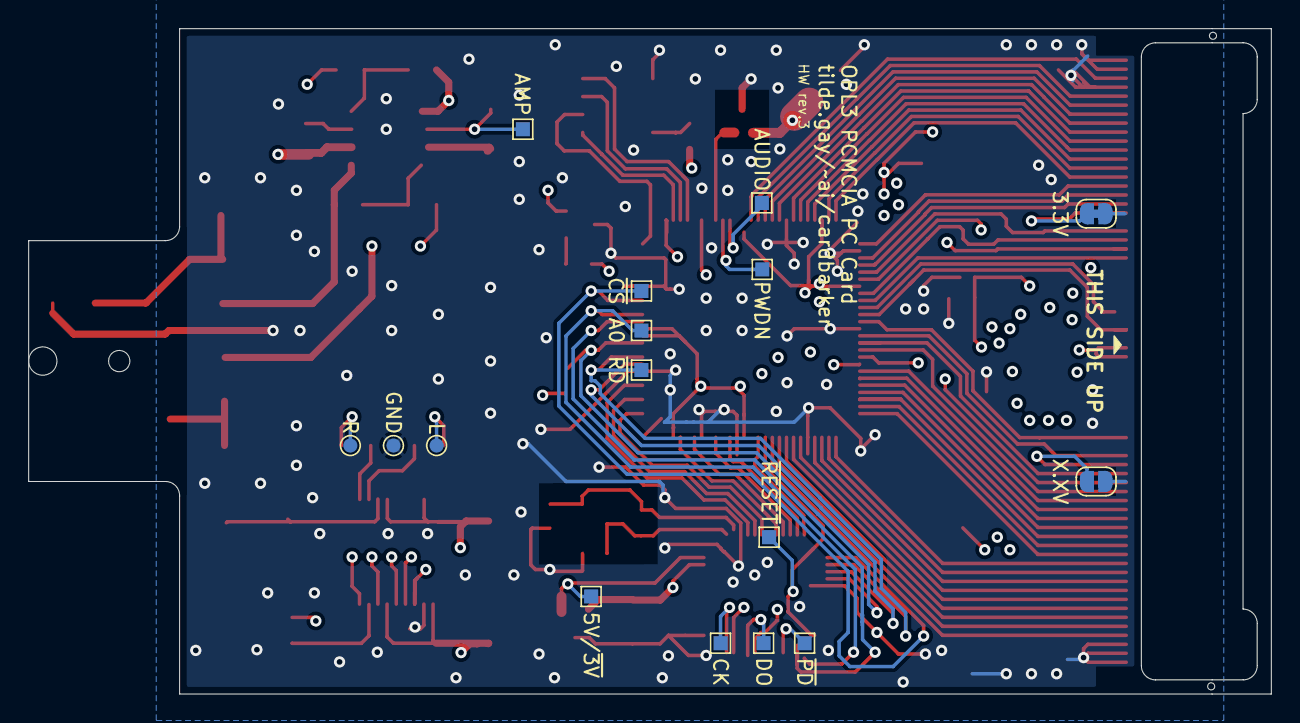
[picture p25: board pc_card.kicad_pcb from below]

Board: 4 copper layers, 87.8 x 47.0 mm, 61 parts (16 on the bottom side), 93 nets.

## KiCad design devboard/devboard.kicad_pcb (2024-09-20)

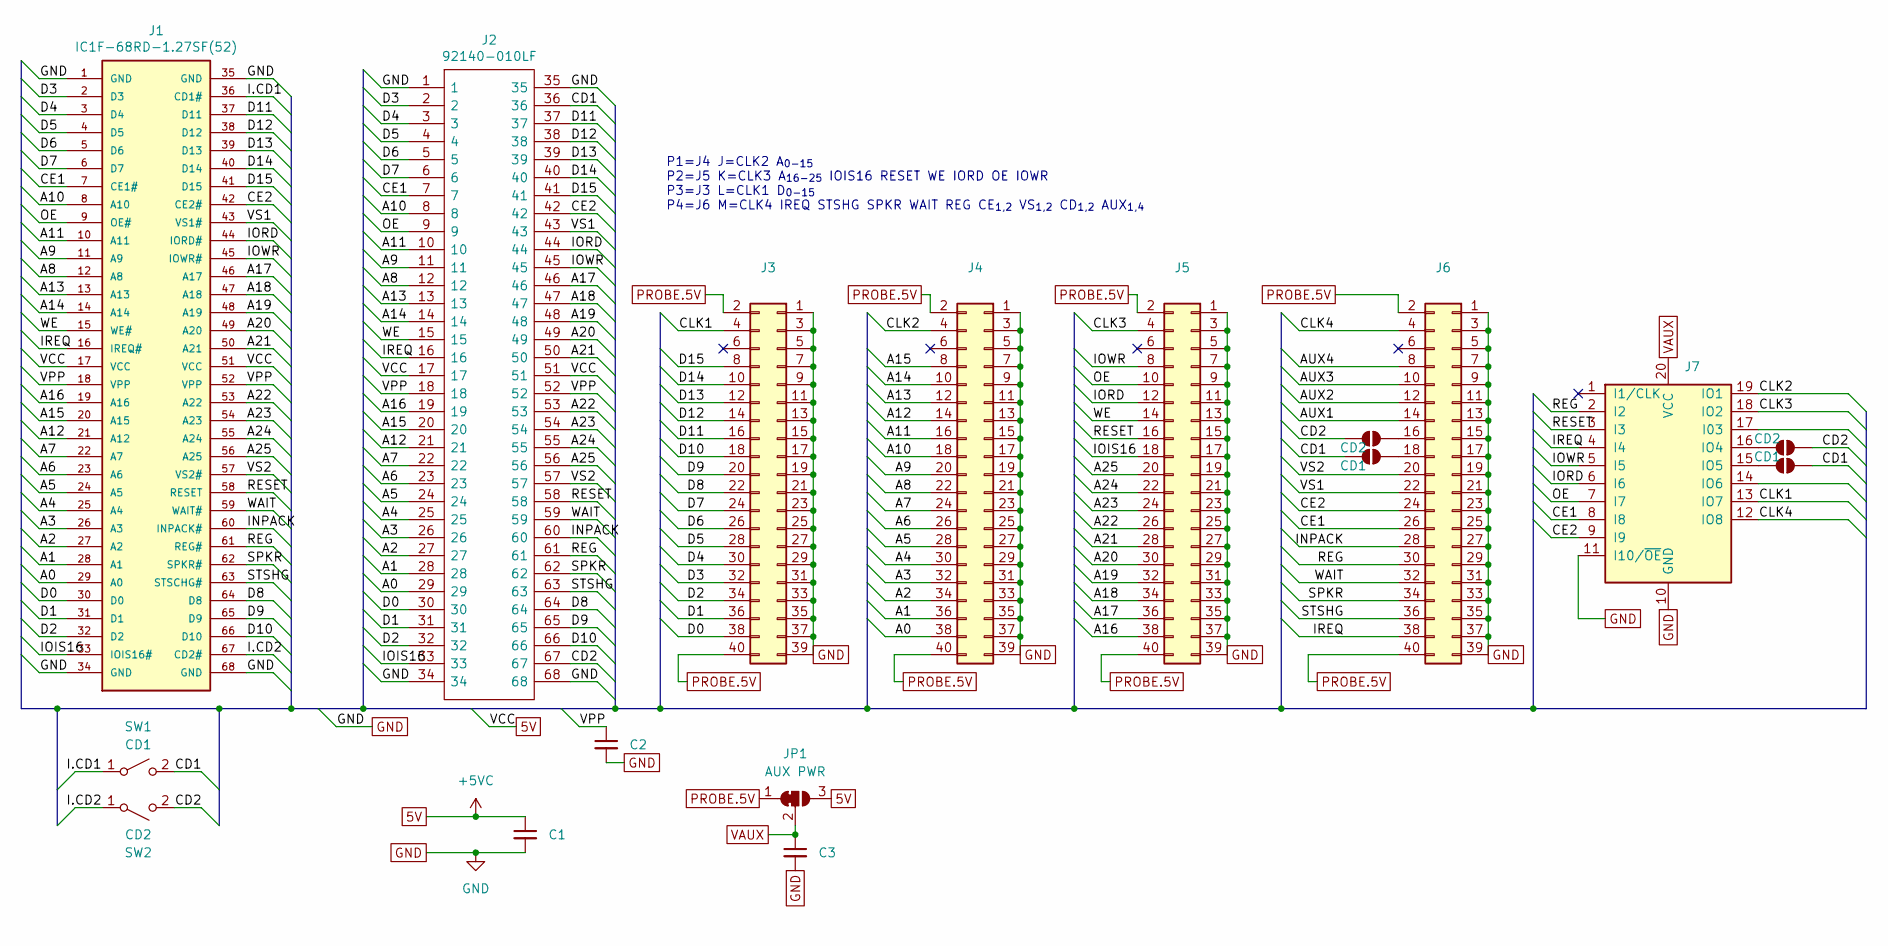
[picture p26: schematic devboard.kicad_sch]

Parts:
C1, C2, C3: 1uF PWR; C_1206_3216Metric_Pad1.33x1.80mm_HandSolder; Mouser Part Number 80-C1206X104G4HACTU
J1: IC1F-68RD-1.27SF(52); 95622003LF
J2: 92140-010LF; 92140010LF; Mouser Part Number 649-92140-010LF
J3: D_{0-15}; Hirose_FH12-40S-0.5SH_1x40-1MP_P0.50mm_Horizontal
J4: A_{0-15}; Hirose_FH12-40S-0.5SH_1x40-1MP_P0.50mm_Horizontal
J5: A_{16-25} IOIS16 RESET WE IORD OE IOWR; Hirose_FH12-40S-0.5SH_1x40-1MP_P0.50mm_Horizontal
J6: IREQ STSHG SPKR WAIT REG CE_{1,2} VS_{1,2} CD_{1,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; Hirose_FH12-40S-0.5SH_1x40-1MP_P0.50mm_Horizontal
J7: REG RESET IREQ IOWR IORD OE CE_{1,2}; DIP-20_W7.62mm
JP1: AUX PWR; SolderJumper-3_P1.3mm_Bridged12_Pad1.0x1.5mm
JP2, JP5: CD2; SolderJumper-2_P1.3mm_Open_RoundedPad1.0x1.5mm
JP3, JP4: CD1; SolderJumper-2_P1.3mm_Open_RoundedPad1.0x1.5mm
SW1: CD1; D_DO-15_P3.81mm_Vertical_AnodeUp
SW2: CD2; D_DO-15_P3.81mm_Vertical_AnodeUp

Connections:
5V: C1.1, J1.17 (VCC), J1.51 (VCC), J2.17, J2.51, JP1.3 (B)
/A0: J1.29 (A0), J2.29, J4.38
/A1: J1.28 (A1), J2.28, J4.36
/A2: J1.27 (A2), J2.27, J4.34
/A3: J1.26 (A3), J2.26, J4.32
/A4: J1.25 (A4), J2.25, J4.30
/A5: J1.24 (A5), J2.24, J4.28
/A6: J1.23 (A6), J2.23, J4.26
/A7: J1.22 (A7), J2.22, J4.24
/A8: J1.12 (A8), J2.12, J4.22
/A9: J1.11 (A9), J2.11, J4.20
/A10: J1.8 (A10), J2.8, J4.18
/A11: J1.10 (A11), J2.10, J4.16
/A12: J1.21 (A12), J2.21, J4.14
/A13: J1.13 (A13), J2.13, J4.12
/A14: J1.14 (A14), J2.14, J4.10
/A15: J1.20 (A15), J2.20, J4.8
/A16: J1.19 (A16), J2.19, J5.38
/A17: J1.46 (A17), J2.46, J5.36
/A18: J1.47 (A18), J2.47, J5.34
/A19: J1.48 (A19), J2.48, J5.32
/A20: J1.49 (A20), J2.49, J5.30
/A21: J1.50 (A21), J2.50, J5.28
/A22: J1.53 (A22), J2.53, J5.26
/A23: J1.54 (A23), J2.54, J5.24
/A24: J1.55 (A24), J2.55, J5.22
/A25: J1.56 (A25), J2.56, J5.20
/AUX1: J6.14
/AUX2: J6.12
/AUX3: J6.10
/AUX4: J6.8
/CD1: J2.36, JP3.2 (B), JP4.1 (A), SW1.2 (B)
/CD2: J2.67, JP2.2 (B), JP5.1 (A), SW2.2 (B)
/CE1: J1.7 (CE1#), J2.7, J6.26, J7.8 (I8)
/CE2: J1.42 (CE2#), J2.42, J6.24, J7.9 (I9)
/CLK1: J3.4, J7.13 (IO7)
/CLK2: J4.4, J7.19 (IO1)
/CLK3: J5.4, J7.18 (IO2)
/CLK4: J6.4, J7.12 (IO8)
/D0: J1.30 (D0), J2.30, J3.38
/D1: J1.31 (D1), J2.31, J3.36
/D2: J1.32 (D2), J2.32, J3.34
/D3: J1.2 (D3), J2.2, J3.32
/D4: J1.3 (D4), J2.3, J3.30
/D5: J1.4 (D5), J2.4, J3.28
/D6: J1.5 (D6), J2.5, J3.26
/D7: J1.6 (D7), J2.6, J3.24
/D8: J1.64 (D8), J2.64, J3.22
/D9: J1.65 (D9), J2.65, J3.20
/D10: J1.66 (D10), J2.66, J3.18
/D11: J1.37 (D11), J2.37, J3.16
/D12: J1.38 (D12), J2.38, J3.14
/D13: J1.39 (D13), J2.39, J3.12
/D14: J1.40 (D14), J2.40, J3.10
/D15: J1.41 (D15), J2.41, J3.8
/I.CD1: J1.36 (CD1#), SW1.1 (A)
/I.CD2: J1.67 (CD2#), SW2.1 (A)
/INPACK: J1.60 (INPACK#), J2.60, J6.28
/IOIS16: J1.33 (IOIS16#), J2.33, J5.18
/IORD: J1.44 (IORD#), J2.44, J5.12, J7.6 (I6)
/IOWR: J1.45 (IOWR#), J2.45, J5.8, J7.5 (I5)
/IREQ: J1.16 (IREQ#), J2.16, J6.38, J7.4 (I4)
/OE: J1.9 (OE#), J2.9, J5.10, J7.7 (I7)
/REG: J1.61 (REG#), J2.61, J6.30, J7.2 (I2)
/RESET: J1.58 (RESET), J2.58, J5.16, J7.3 (I3)
/SPKR: J1.62 (SPKR#), J2.62, J6.34
/STSHG: J1.63 (STSCHG#), J2.63, J6.36
/VPP: C2.1, J1.18 (VPP), J1.52 (VPP), J2.18, J2.52
/VS1: J1.43 (VS1#), J2.43, J6.22
/VS2: J1.57 (VS2#), J2.57, J6.20
/WAIT: J1.59 (WAIT#), J2.59, J6.32
/WE: J1.15 (WE#), J2.15, J5.14
GND: C1.2, C2.2, C3.2, J1.1 (GND), J1.34 (GND), J1.35 (GND), J1.68 (GND), J2.1, J2.34, J2.35, J2.68, J3.1, J3.3, J3.5, J3.7, J3.9, J3.11, J3.13, J3.15, J3.17, J3.19, J3.21, J3.23, J3.25, J3.27, J3.29, J3.31, J3.33, J3.35, J3.37, J3.39, J4.1, J4.3, J4.5, J4.7, J4.9, J4.11, J4.13, J4.15, J4.17, J4.19, J4.21, J4.23, J4.25, J4.27, J4.29, J4.31, J4.33, J4.35, J4.37, J4.39, J5.1, J5.3, J5.5, J5.7, J5.9, J5.11, J5.13, J5.15, J5.17, J5.19, J5.21, J5.23, J5.25, J5.27, J5.29, J5.31, J5.33, J5.35, J5.37, J5.39, J6.1, J6.3, J6.5, J6.7, J6.9, J6.11, J6.13, J6.15, J6.17, J6.19, J6.21, J6.23, J6.25, J6.27, J6.29, J6.31, J6.33, J6.35, J6.37, J6.39, J7.10 (GND), J7.11 (I10/~OE)
unnamed: J6.16, JP5.2 (B)
unnamed: J6.18, JP4.2 (B)
unnamed: J7.16 (IO4), JP2.1 (A)
unnamed: J7.15 (IO5), JP3.1 (A)
PROBE.5V: J3.2, J3.40, J4.2, J4.40, J5.2, J5.40, J6.2, J6.40, JP1.1 (A)
VAUX: C3.1, J7.20 (VCC), JP1.2 (C)

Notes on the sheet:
P1=J4 J=CLK2 A_{0-15} P2=J5 K=CLK3 A_{16-25} IOIS16 RESET WE IORD OE IOWR P3=J3 L=CLK1 D_{0-15} P4=J6 M=CLK4 IREQ STSHG SPKR WAIT REG CE_{1,2} VS_{1,2} CD_{1,2} AUX_{1,4}

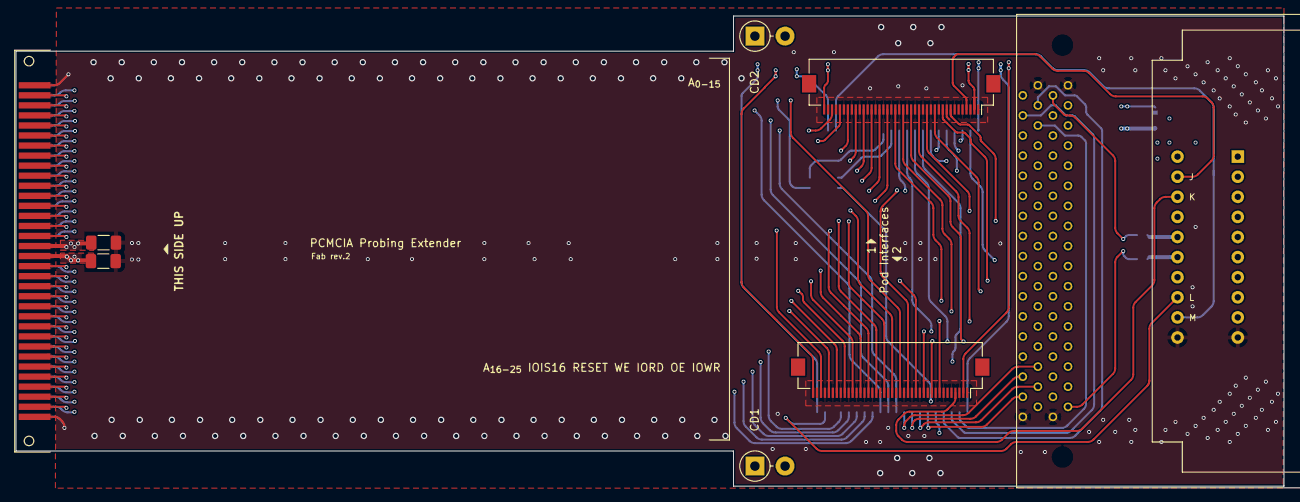
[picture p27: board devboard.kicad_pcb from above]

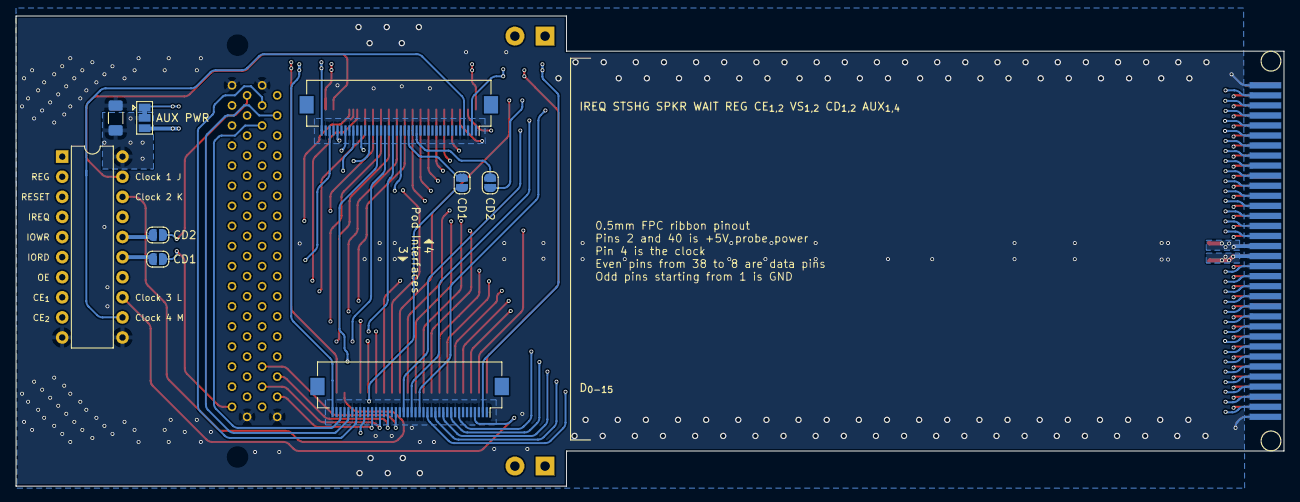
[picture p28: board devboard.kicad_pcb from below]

Board: 4 copper layers, 160.3 x 59.4 mm, 17 parts (9 on the bottom side), 75 nets.

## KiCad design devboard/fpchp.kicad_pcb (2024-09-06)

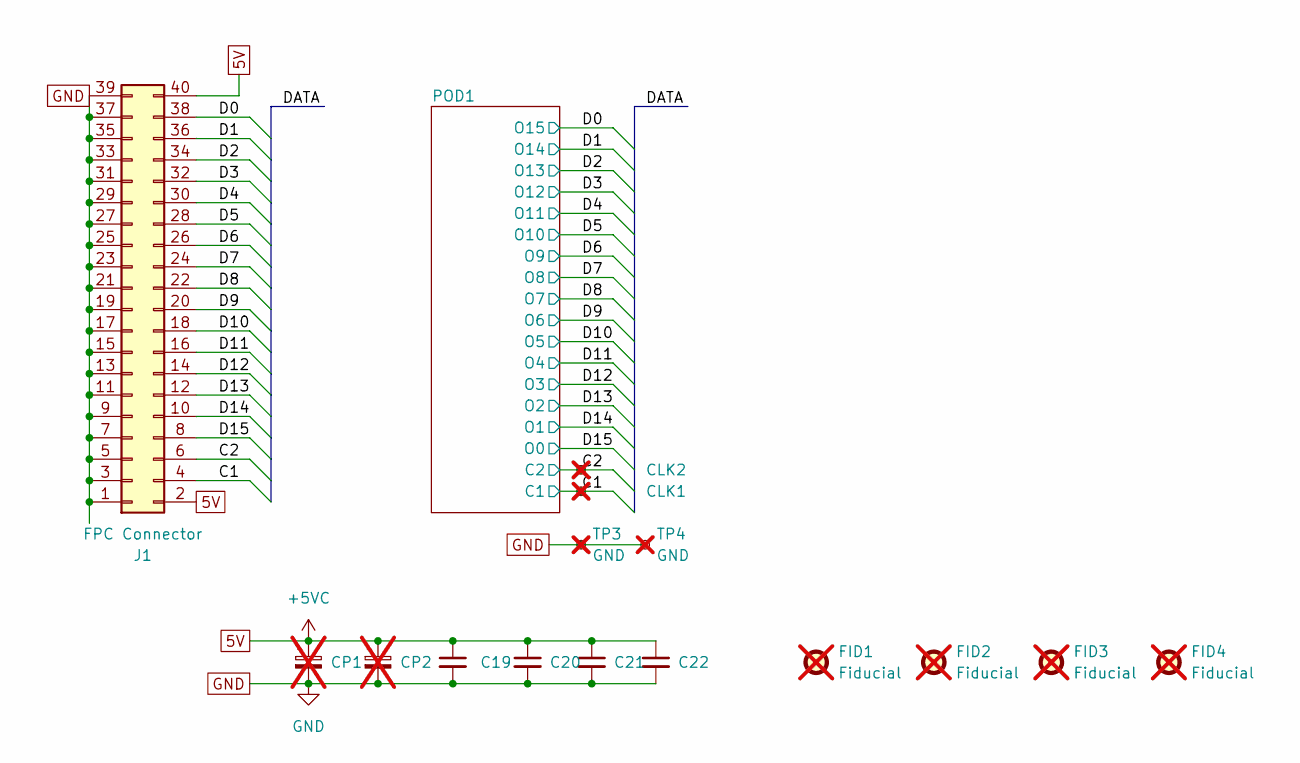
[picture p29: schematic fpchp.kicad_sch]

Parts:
C19, C20, C21, C22: 1uF PWR; C_1206_3216Metric_Pad1.33x1.80mm_HandSolder; Mouser Part Number 80-C1206X104G4HACTU
CP1, CP2: PPWR; CP_EIA-7343-31_Kemet-D; Mouser Part Number 667-EEF-CS1D100R; not fitted
FID1, FID2, FID3, FID4: Fiducial; not fitted
J1: FPC Connector; Hirose_FH12-40S-0.5SH_1x40-1MP_P0.50mm_Horizontal
TP1: CLK2; TestPoint_THTPad_1.0x1.0mm_Drill0.5mm; not fitted
TP2: CLK1; TestPoint_THTPad_1.0x1.0mm_Drill0.5mm; not fitted
TP3, TP4: GND; TestPoint_THTPad_1.0x1.0mm_Drill0.5mm; not fitted

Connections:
5V: C19.1, C20.1, C21.1, C22.1, CP1.1, CP2.1, J1.2, J1.40; also elsewhere on the board
/C1: J1.4, TP2.1; also elsewhere on the board
/C2: J1.6, TP1.1; also elsewhere on the board
/D0: J1.38; also elsewhere on the board
/D1: J1.36; also elsewhere on the board
/D2: J1.34; also elsewhere on the board
/D3: J1.32; also elsewhere on the board
/D4: J1.30; also elsewhere on the board
/D5: J1.28; also elsewhere on the board
/D6: J1.26; also elsewhere on the board
/D7: J1.24; also elsewhere on the board
/D8: J1.22; also elsewhere on the board
/D9: J1.20; also elsewhere on the board
/D10: J1.18; also elsewhere on the board
/D11: J1.16; also elsewhere on the board
/D12: J1.14; also elsewhere on the board
/D13: J1.12; also elsewhere on the board
/D14: J1.10; also elsewhere on the board
/D15: J1.8; also elsewhere on the board
GND: C19.2, C20.2, C21.2, C22.2, CP1.2, CP2.2, J1.1, J1.3, J1.5, J1.7, J1.9, J1.11, J1.13, J1.15, J1.17, J1.19, J1.21, J1.23, J1.25, J1.27, J1.29, J1.31, J1.33, J1.35, J1.37, J1.39, TP3.1, TP4.1; also elsewhere on the board

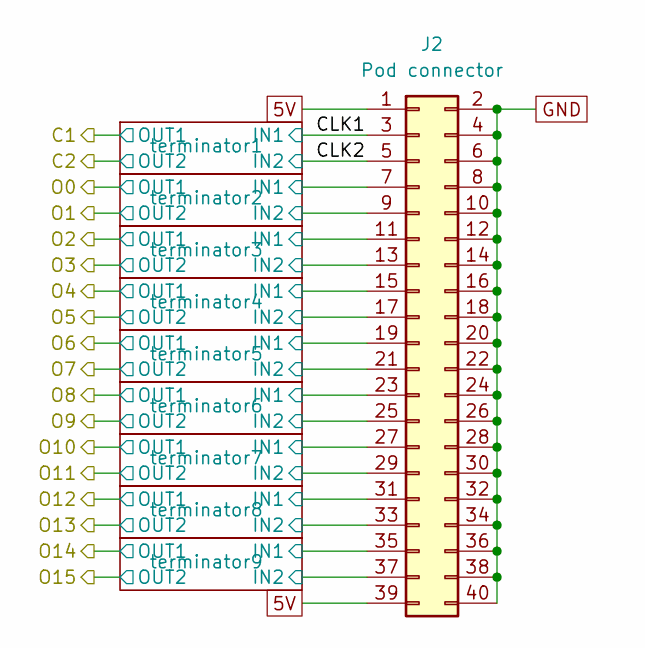
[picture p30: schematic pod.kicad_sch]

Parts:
J2: Pod connector; IDC-Header_2x20_P2.54mm_Vertical

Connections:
5V: J2.1, J2.39; also elsewhere on the board
/POD1/CLK1: J2.3; also elsewhere on the board
/POD1/CLK2: J2.5; also elsewhere on the board
/POD1/terminator2/IN1: J2.7; also elsewhere on the board
/POD1/terminator2/IN2: J2.9; also elsewhere on the board
/POD1/terminator3/IN1: J2.11; also elsewhere on the board
/POD1/terminator3/IN2: J2.13; also elsewhere on the board
/POD1/terminator4/IN1: J2.15; also elsewhere on the board
/POD1/terminator4/IN2: J2.17; also elsewhere on the board
/POD1/terminator5/IN1: J2.19; also elsewhere on the board
/POD1/terminator5/IN2: J2.21; also elsewhere on the board
/POD1/terminator6/IN1: J2.23; also elsewhere on the board
/POD1/terminator6/IN2: J2.25; also elsewhere on the board
/POD1/terminator7/IN1: J2.27; also elsewhere on the board
/POD1/terminator7/IN2: J2.29; also elsewhere on the board
/POD1/terminator8/IN1: J2.31; also elsewhere on the board
/POD1/terminator8/IN2: J2.33; also elsewhere on the board
/POD1/terminator9/IN1: J2.35; also elsewhere on the board
/POD1/terminator9/IN2: J2.37; also elsewhere on the board
GND: J2.2, J2.4, J2.6, J2.8, J2.10, J2.12, J2.14, J2.16, J2.18, J2.20, J2.22, J2.24, J2.26, J2.28, J2.30, J2.32, J2.34, J2.36, J2.38, J2.40; also elsewhere on the board

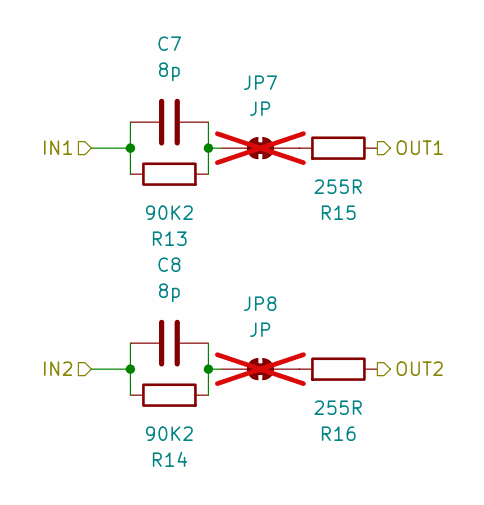
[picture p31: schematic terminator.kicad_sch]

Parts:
C7, C8: 8p; C_0402_1005Metric
JP7, JP8: JP; SolderJumper-2_P1.3mm_Bridged_RoundedPad1.0x1.5mm; not fitted
R13, R14: 90K2; R_0402_1005Metric
R15, R16: 255R; R_0402_1005Metric

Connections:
/D10: R16.1; also elsewhere on the board
/D11: R15.1; also elsewhere on the board
/POD1/terminator4/IN1: C7.2, R13.1; also elsewhere on the board
/POD1/terminator4/IN2: C8.2, R14.1; also elsewhere on the board
unnamed: JP7.1 (A), R15.2
unnamed: C7.1, JP7.2 (B), R13.2
unnamed: JP8.1 (A), R16.2
unnamed: C8.1, JP8.2 (B), R14.2

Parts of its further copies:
C1, C2, C3, C4, C5, C6, C9, C10, C11, C12, C13, C14, C15, C16, C17, C18: 8p; C_0402_1005Metric
JP1, JP2, JP3, JP4, JP5, JP6, JP9, JP10, JP11, JP12, JP13, JP14, JP15, JP16, JP17, JP18: JP; SolderJumper-2_P1.3mm_Bridged_RoundedPad1.0x1.5mm; not fitted
R1, R2, R5, R6, R9, R10, R17, R18, R21, R22, R25, R26, R29, R30, R33, R34: 90K2; R_0402_1005Metric
R3, R4, R7, R8, R11, R12, R19, R20, R23, R24, R27, R28, R31, R32, R35, R36: 255R; R_0402_1005Metric

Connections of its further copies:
/C1: R3.1; also elsewhere on the board
/C2: R4.1; also elsewhere on the board
/D0: R36.1; also elsewhere on the board
/D1: R35.1; also elsewhere on the board
/D2: R32.1; also elsewhere on the board
/D3: R31.1; also elsewhere on the board
/D4: R28.1; also elsewhere on the board
/D5: R27.1; also elsewhere on the board
/D6: R24.1; also elsewhere on the board
/D7: R23.1; also elsewhere on the board
/D8: R20.1; also elsewhere on the board
/D9: R19.1; also elsewhere on the board
/D12: R12.1; also elsewhere on the board
/D13: R11.1; also elsewhere on the board
/D14: R8.1; also elsewhere on the board
/D15: R7.1; also elsewhere on the board
/POD1/CLK1: C1.2, R1.1; also elsewhere on the board
/POD1/CLK2: C2.2, R2.1; also elsewhere on the board
/POD1/terminator2/IN1: C3.2, R5.1; also elsewhere on the board
/POD1/terminator2/IN2: C4.2, R6.1; also elsewhere on the board
/POD1/terminator3/IN1: C5.2, R9.1; also elsewhere on the board
/POD1/terminator3/IN2: C6.2, R10.1; also elsewhere on the board
/POD1/terminator5/IN1: C9.2, R17.1; also elsewhere on the board
/POD1/terminator5/IN2: C10.2, R18.1; also elsewhere on the board
/POD1/terminator6/IN1: C11.2, R21.1; also elsewhere on the board
/POD1/terminator6/IN2: C12.2, R22.1; also elsewhere on the board
/POD1/terminator7/IN1: C13.2, R25.1; also elsewhere on the board
/POD1/terminator7/IN2: C14.2, R26.1; also elsewhere on the board
/POD1/terminator8/IN1: C15.2, R29.1; also elsewhere on the board
/POD1/terminator8/IN2: C16.2, R30.1; also elsewhere on the board
/POD1/terminator9/IN1: C17.2, R33.1; also elsewhere on the board
/POD1/terminator9/IN2: C18.2, R34.1; also elsewhere on the board
unnamed: JP1.1 (A), R3.2
unnamed: C1.1, JP1.2 (B), R1.2
unnamed: JP2.1 (A), R4.2
unnamed: C2.1, JP2.2 (B), R2.2
unnamed: JP3.1 (A), R7.2
unnamed: C3.1, JP3.2 (B), R5.2
unnamed: JP4.1 (A), R8.2
unnamed: C4.1, JP4.2 (B), R6.2
unnamed: JP5.1 (A), R11.2
unnamed: C5.1, JP5.2 (B), R9.2
unnamed: JP6.1 (A), R12.2
unnamed: C6.1, JP6.2 (B), R10.2
unnamed: JP9.1 (A), R19.2
unnamed: C9.1, JP9.2 (B), R17.2
unnamed: JP10.1 (A), R20.2
unnamed: C10.1, JP10.2 (B), R18.2
unnamed: JP11.1 (A), R23.2
unnamed: C11.1, JP11.2 (B), R21.2
unnamed: JP12.1 (A), R24.2
unnamed: C12.1, JP12.2 (B), R22.2
unnamed: JP13.1 (A), R27.2
unnamed: C13.1, JP13.2 (B), R25.2
unnamed: JP14.1 (A), R28.2
unnamed: C14.1, JP14.2 (B), R26.2
unnamed: JP15.1 (A), R31.2
unnamed: C15.1, JP15.2 (B), R29.2
unnamed: JP16.1 (A), R32.2
unnamed: C16.1, JP16.2 (B), R30.2
unnamed: JP17.1 (A), R35.2
unnamed: C17.1, JP17.2 (B), R33.2
unnamed: JP18.1 (A), R36.2
unnamed: C18.1, JP18.2 (B), R34.2

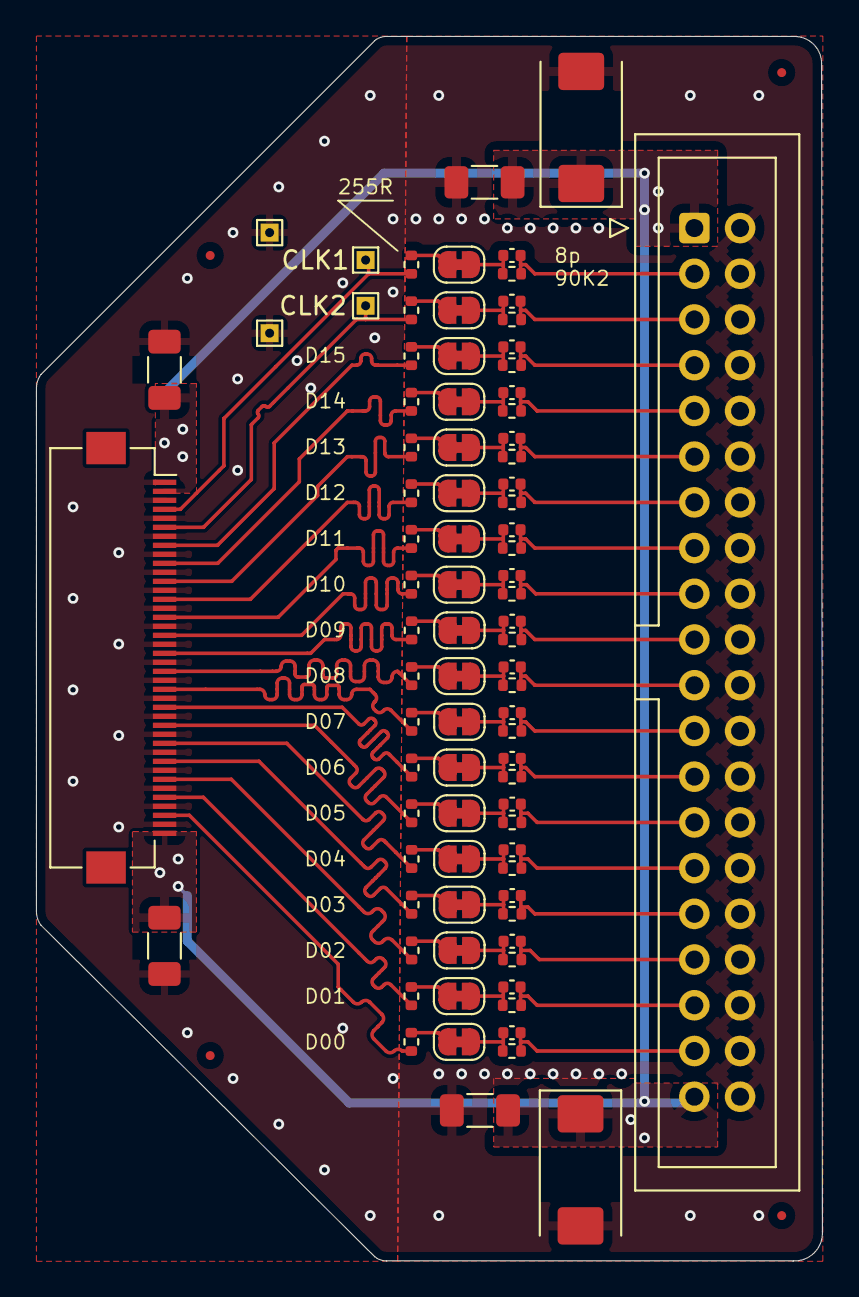
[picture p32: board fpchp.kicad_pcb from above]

Board: 2 copper layers, 43.7 x 68.0 mm, 88 parts (0 on the bottom side), 74 nets.

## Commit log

2021-11-29 BOM, tracks, cleanup
    [pc_card_sound_barker-B_Cu.gbr, pc_card_sound_barker-B_Fab.gbr, pc_card_sound_barker-B_Mask.gbr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]
2021-11-29 remove pull-downs for unused address lines
    [pc_card_sound_barker-B_Cu.gbr, pc_card_sound_barker-B_Fab.gbr, pc_card_sound_barker-B_Mask.gbr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]
2021-11-30 eeprom is isolated for onboard programming
    [pc_card_sound_barker-B_Cu.gbr, pc_card_sound_barker-B_Fab.gbr, pc_card_sound_barker-B_Mask.gbr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]
2021-12-05 devboard prototype
    [devboard-B_Cu.gbr, devboard-B_Mask.gbr, devboard-B_Paste.gbr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]
2024-08-06 new devboard
    Adding 4 x 40 lines 0.5mm FPC ribbon connectors, 16 probing lines each.
    [devboard-B_Cu.gbr, devboard-B_Mask.gbr, devboard-B_Paste.gbr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]
2024-08-06 update to KiCad 8.0.3
    [devboard.sch, pc_card.kicad_pcb, pc_card.kicad_sch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]
2024-08-09 devboard; finishing 4L card
    [92140-010LFc.stp, devboard.kicad_pcb, pc_card.kicad_pcb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]
2024-08-12 render, stl
    [pcb_bracket.stl]
2024-08-31 devboard to hp16xx adapter fab.rev 2
    [fpchp.csv, fpchp.kicad_pcb, fpchp.kicad_sch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]
2024-08-31 ground reshuffle
    [pc_card.kicad_pcb]
2024-09-06 hp adapter rev.2
    [bottom-case.step, fpchp.kicad_pcb, fpchp.kicad_sch]
2024-09-08 card hw rev 2 to manufacture
    [92140-010LFc.stp, pc_card.kicad_pcb, pc_card.kicad_sch]
2024-09-08 docs, stl
    [fpchp.stl, pc_card.kicad_pcb]
2024-09-20 pld, docs
    [devboard.kicad_sch, pc_card.kicad_pcb]
2024-09-20 devboard test
    [devboard.kicad_pcb, devboard.kicad_sch]
2025-02-06 hw rev3
    * reDfMing the card so the connector can be assembled easier
    * added software and specs
    [pc_card.kicad_pcb, pc_card.kicad_sch]
2025-02-06 fiddling with connector
    [5146228-4.stp, 5146547-1.stp, 92140-010LFc.stp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]
2025-02-07 socket assembly
    [pc_card.kicad_pcb, pc_card.kicad_sch]
2025-02-07 messing with xtal
    [ECS-320-CDX-2291.STEP, devboard.kicad_sch, pc_card.kicad_pcb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]
2025-07-01 INF file
    [pc_card.kicad_pcb, pc_card.kicad_sch]
2025-07-03 even more minimalist driver, fw generation works for windows
